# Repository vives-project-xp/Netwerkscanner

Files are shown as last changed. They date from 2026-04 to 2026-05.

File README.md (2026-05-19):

# Network Scanner





## Beschrijving

dit is een project voor het ontwikkelen van een netwerkscanner die apparaten binnen een lokaal netwerk kan detecteren en identificeren. Het project omvat zowel hardware- als softwarecomponenten en is bedoeld voor educatieve doeleinden binnen VIVES.

dit word uitgevoerd volgens de agile methodologie, met regelmatige sprints en feedback loops om continue verbetering te waarborgen.

de studenten die aan dit project werken zijn:

| Naam | github |
|---|---|
| Kyell De Windt | [](https://github.com/kyell182) |
| Ilias Lagrane | [](https://github.com/IliasLagrane) |
| Kevin Bakeland | [](https://github.com/KevinBakeland) |
| Spotnit | [](https://github.com/Spotnit) |

## testen positie bepaling
[testen van positie bepaling via wifi](./doc/positiebepaling_ideas/esp_testen.md)

## Functies

- [ ] netwerkscanning ( inkaart bregen van apparaten binnen een lokaal netwerk)
- [+] heatmap visualisatie van netwerkactiviteit
- [+] rapportage en logging van gedetecteerde apparaten
- [+] real-time monitoring dashboard

## Projectstructuur

```plaintext

Netwerkscanner/
├── hardware/
│   ├── [Hardware configuratie/schema's]
│   └── README.md
├── software/
│   ├── [Broncode bestanden]
│   └── README.md
├── doc/
│   ├── brainstorm.drawio
│   ├── RaspberryPI.md
│   └── [Overige documentatie]
├── README.md
└── .gitignore
```

## Installatie
zie documentatie

### Hardware Setup

[Beschrijving van hardware setup stappen]

### Software Setup

```bash
# Clone het repository
git clone https://github.com/vives-project-xp/Netwerkscanner.git

# Installeer dependencies
[Installatiecommando's]

# Configureer het project
[Configuratiestappen]
```

## Gebruik

```bash
# Voorbeeld command
[Hoe de scanner te gebruiken]
```

### Voorbeelden

[Praktische voorbeelden met output]

## Technologie Stack

- **Taal**: [Bijv. Python, C++, etc.]
- **Hardware**: [Bijv. Raspberry Pi, Arduino, etc.]
- **Dependencies**: [Bijv. nmap, socket, etc.]

## Status

- [x] Planning
- [x] Development
- [x] Testing
- [x] Documentation
- [x] Deployment

- [RaspberryPI Setup](doc/RaspberryPI.md)
- [Brainstorm Diagram](doc/brainstorm.drawio)
 - [Netwerkscanner Dash gebruikershandleiding](doc/netwerkscanner-dash/README.md)

##  Documentatie

### Software documentatie

#### Netwerkscanner
- [API C++ documentatie](doc/software_doc/netwerkscanner_doc/api_cpp_doc.md)
- [Device menu](doc/software_doc/netwerkscanner_doc/device_menu.md)
- [HTTP POST C++ documentatie](doc/software_doc/netwerkscanner_doc/http_post_cpp_doc.md)
- [OTA server documentatie](doc/software_doc/netwerkscanner_doc/ota_server_doc.md)
- [Screen C++ documentatie](doc/software_doc/netwerkscanner_doc/screen_cpp_doc.md)
- [Time sync documentatie](doc/software_doc/netwerkscanner_doc/time_sync_doc.md)

#### WiFi API
- [App Python documentatie](doc/software_doc/wifi-api_doc/app_py_doc.md)
- [Fingerprint Python documentatie](doc/software_doc/wifi-api_doc/fingerprint_py_doc.md)

### Overige documenten
- [Brainstorm](doc/brainstorm.drawio)
- [Fingerprint Python doc](doc/docFingerprint.py.md)
- [Projectfiche Netwerk Scanner](doc/PX%204%20-%20Projectfiche%20Netwerk%20Sca....md)
- [Roadmap](doc/readmap.md)

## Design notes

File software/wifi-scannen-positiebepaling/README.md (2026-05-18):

Deze map bevat de code voor de esp32 wroom. Deze werden gebruikt om verschilende indoor positie bepalings technieken te testen en uit te proberen.

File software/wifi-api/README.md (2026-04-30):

# Uitleg
Dit is de map met de Flask‑API en de MariaDB‑database.  
De API ontvangt Wi‑Fi scans van de ESP32, slaat ze op en bepaalt automatisch een locatie via Wi‑Fi fingerprinting.  
Je kan via de API posten naar de database en waardes kunnen opvragen.

## Hoe het werkt
- **Fingerprint**: een table waar al onze manueele scans inzitten die we gebruiken voor locatie bepaling
- **heatmap**: alle gevonden netwerken per scan gaan in deze table.
- **dev**: een table die je alleen kan opvragen met data dat niet wordt verandert, wordt gebruikt mocht een table corrupt zijn zodat dat we nog waardes kunnen opvragen.
- De fingerprinting file vergelijkt nieuwe scans met manual‑scans en vult automatisch x,y in.

## Docker
Je kan de containers starten:
- vanuit de projectroot: `docker compose up`

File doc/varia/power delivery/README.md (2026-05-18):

Deze folder is onderzoek die gedaan is maar uiteindelijk niet gebruikt.
De espc5 module (FireBeetle 2 ESP32-C5)die wij gebruiken heeft een batterij connector met bijhoorende beveiliging regeling.

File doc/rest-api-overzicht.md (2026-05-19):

# REST API overzicht

```mermaid
flowchart LR
  esp[ESP32 / Netwerkscanner] -->|GET /time| api[Flask REST API\nsoftware/wifi-api/api/app.py]
  esp -->|POST /upload| api

  ui[Dashboard / React app] -->|GET /api/heatmap| vite[Vite proxy\nsoftware/netwerkscanner-dash/vite.config.js]
  ui -->|GET/POST /projects/central.json| upload[Upload server\nsoftware/netwerkscanner-dash/file-upload-server.js]
  ui -->|POST /upload| upload

  vite -->|rewrite /api -> /| api
  upload -->|JSON + files| json[(software/assets/projectdata/central.json\n+ uploaded images)]

  api -->|MariaDB| db[(MariaDB\nheatmap, fingerprint, dev)]

  api -->|GET /heatmap| db
  api -->|GET /fingerprint| db
  api -->|GET /dev| db
  api -->|GET /predict/<id>| db
```

## Kort

- De hoofd-REST-API is de Flask-service in `software/wifi-api/api/app.py`.
- De dashboard gebruikt Vite als proxy voor `/api/*`.
- Gebouw- en vloerdata worden opgeslagen via de uploadserver in JSON en uploads in `software/assets/projectdata`.
- Scan- en fingerprintdata gaan naar MariaDB.

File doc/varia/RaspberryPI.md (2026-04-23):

#Netwerk Scanner
---

## Raspberry Pi 4

### USB
| Product / Antenne | Type / Opmerking | Frequenties | Extra info / Link |
| --- | --- | --- | --- |
| **TP‑Link Archer T2U Plus** | USB Wi‑Fi adapter met externe antennes | 2.4 / 5 GHz Dual‑Band | Goede all‑round keuze, dual-band, Linux-compatibel |
| **TP‑Link Archer T4U AC1300** | USB Wi‑Fi adapter met externe antennes | 2.4 / 5 GHz | Sterke prestaties, externe antennes |
| **BrosTrend Linux WiFi Adapter** | USB Wi‑Fi adapter | Dual-Band | Ontworpen voor Linux, goede antennes |
| **Hoco HI34 WiFi6 USB Dual Antenna** | USB Wi‑Fi adapter | Wi‑Fi 5/6 (2.4 / 5 GHz) | Wi‑Fi 6, externe antennes |
| **TP‑Link TL‑WN722N** | USB Wi‑Fi adapter met externe antenne | 2.4 GHz | Klassiker voor Raspberry Pi (2.4 GHz) |
| **Raspberry Pi sc0480 Antennekit** | Externe antenne (SMA) voor Compute Module | Dual-band Wi-Fi | Specifiek voor **CM4 externe antenne** [Kamami.pl](https://kamami.pl/en/accessories-for-raspberry-pi/1188448-sc0480-24g5g-wifi-antenna-for-raspberry-pi-compute-module-4.html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) + antenne connector dongle to usb|
| **Compute Module CM4 Antenna Kit** | Antennekit met U.FL-SMA kabel | Dual-band Wi-Fi | Kit voor **CM4**, inclusief kabel [asdstore.de](https://www.asdstore.de/cm4-cm5-antenna-kit_1?utm_source=chatgpt.com) |
| **Compatible Antenna for CM4/5** | Basis antenne voor CM4/5 | Dual-band Wi-Fi | Budget-antenne voor Compute Module + antenne connector dongle to usb |
| **Waveshare Compatibel Antenne** | Externe antenne voor CM4/5 | Dual-band Wi-Fi | Horn-antenne met SMA aansluiting [RobotShop USA](https://www.robotshop.com/products/waveshare-compatible-antenna-for-raspberry-pi-compute-module-4-24g-5g-wifi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) + antenne connector dongle to usb |
| **Waveshare CM4/5 Antenna Kit** | Complete antennekit | Dual-band Wi-Fi | Kit met accessoires, CM4/5 compatible 

### Niet USB
| Antenne | Frequentie |  Connector type | Opmerkingen |
| --- | ---: | :---: | --- |
| **[Otronic 2.4GHz WiFi antenne met SMA naar uFL/IPEX]()** | 2.4 GHz | SMA → u.FL/IPEX | Klein externe antenne met adapter → ideaal voor u.FL antenne‑connector ESP‑boards. |
| **[SMA 2.4GHz 2dB antenne]()** | 2.4 GHz | SMA | Basis omnidirectionele antenne – vereist adapter naar u.FL/IPEX om te koppelen aan ESP. |
| **[Equipment 2.4GHz antenne]()** | 2.4 GHz | (SMA/RP‑SMA)  | Externe antenne – converter kabel nodig voor aansluiting op ESP boards met u.FL. |
| **[Pinwheel 2.4GHz SMA antenne]()** | 2.4 GHz | SMA | Robuuste antenne met SMA – combineer met u.FL‑SMA pigtail. |
| **[JARFT 2.4GHz WiFi Omni antenne]()** | 2.4 GHz | RP‑SMA | All‑round antenne – goede keuze voor IoT projecten, adapter vereist. |
| **[2.4GHz Duck Antenna RP‑SMA]()** | 2.4 GHz | RP‑SMA | Whip‑antenne met rubber dop; past via adapter op boards met u.FL/IPEX. |
| **[2.4GHz Whip Rubber Antenna]()** | 2.4 GHz | SMA | Eenvoudige whip antenne – werkt met adapters. |
| **[Alfa Network 2.4GHz 15dBi omni antenne]()** | 2.4 GHz | RP‑SMA | Hoog‑gain omni antenne – geschikt voor lange‑afstand Wi‑Fi (met adapter). |
                                                                                                                                                                |
| Module | CPU / Core | Wi-Fi | Bluetooth | Externe antenne | Voordelen | Nadelen | Aanbevolen gebruik |
|---|---|---|---|---|---|---|---|
| ESP32-WROOM-32U | Dual-core 240 MHz | 2.4 GHz | BT + BLE | Ja (u.FL) | Zeer stabiel, veel support, goed voor promiscuous mode | Iets hoger verbruik | Allround netwerk scanner |
| ESP32-S3-WROOM-1U | Dual-core 240 MHz LX7 | 2.4 GHz | BLE 5 | Ja (u.FL) | Native USB, moderner, betere power management | Iets duurder | USB logging + data analyse |
| ESP32-C3-WROOM-02U | Single-core 160 MHz RISC-V | 2.4 GHz  | BLE 5 | Ja (u.FL) | Energiezuinig, compact, goedkoop | Minder rekenkracht | Batterij-geoptimaliseerde scanner |
| ESP32-C6-WROOM-1U | Single-core 160 MHz RISC-V | 2.4 GHz (Wi-Fi 6) | BLE 5 + 802.15.4 | Ja (u.FL) | Nieuwste generatie, toekomstgericht | Nog minder mature support | Experimenteel / Wi-Fi 6 scanning |
| ESP8266 (ESP-07) | Single-core 80–160 MHz | 2.4 GHz | Geen | Ja (u.FL) | Zeer goedkoop | Beperkte sniffing support, ouder | Low-budget project |

| Optie | Type | Nominale spanning | Capaciteit (typisch) | Extra elektronica nodig | Voordelen | Nadelen | Aanbevolen gebruik |
|---|---|---|---|---|---|---|---|
| USB Powerbank (5V output) | Li-ion intern | 5V uitgang | 5.000–20.000 mAh | Nee | Plug & play, ingebouwde bescherming, stabiele 5V | Minder controle over power management | Snelle prototype / eenvoudige voeding |
| 1x 18650 Li-ion cel | Li-ion | 3.7V (4.2V max) | 2.000–3.500 mAh | Ja (TP4056 + boost) | Compact, goedkoop, vervangbaar | Extra laad- en boostcircuit nodig | Custom compacte scanner |
| 2x 18650 in serie (2S) | Li-ion | 7.4V (8.4V max) | 2.000–3.500 mAh | Ja (BMS + buck converter)| Hogere efficiëntie bij buck naar 5V | Complexer, BMS vereist | Langere runtime systemen |
| 1S LiPo batterij | LiPo | 3.7V (4.2V max) | 500–5.000 mAh | Ja (laadmodule + evt. boost) | Licht, plat, ideaal voor handheld | Mechanisch gevoeliger | Compacte handheld scanner |
| 2S LiPo batterij | LiPo | 7.4V | 1.000–5.000 mAh | Ja (BMS + buck) | Efficiënte spanningsregeling mogelijk | Hogere complexiteit | Geavanceerde builds |
| 18650 DIY Powerbank module | Li-ion (18650) | 5V uitgang | Afhankelijk van cel  | Nee (meestal ingebouwd)  | Zelf cellen kiezen, 5V output | Kwaliteit varieert | Semi-custom oplossing |

## Displays:

| 5 inch touchscreen 52 euro |https://www.hobbyelectronica.nl/product/5-0-ips-capacitive-touchscreen-esp32-8048s050c-i/ |
| 4.3 inch touchscreen 39 euro | https://www.hobbyelectronica.nl/product/4-3-ips-capacitive-touchscreen-esp32-8048s043c-i |
| 3.5 inch touch 24 euro (specifiek voor ESP) | https://www.hobbyelectronica.nl/product/esp32-3-5-tft-480-320-touch/ |

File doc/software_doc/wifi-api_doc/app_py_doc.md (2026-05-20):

# APP.PY

Dit is de servercode van het project.

Via deze code weet de server wat hij moet doen met de data die de ESP verstuurt.

De server is ontwikkeld in Python met het Flask-framework.  
Hij ontvangt scandata van de ESP en slaat deze op in een MariaDB-database via een API die beschikbaar is voor het dashboard.

---

# FLASK ROUTES

Flask maakt gebruik van routes.

De server draait op:

```text
http://10.20.10.24:8081
```

## Beschikbare routes

---

## `/upload`

Dit is het eindpunt waar de ESP zijn data naartoe stuurt.

### Werking

- De server controleert of de ontvangen JSON geldig is
- Er wordt een nieuwe `scan_id` aangemaakt
  - dit is een uniek nummer voor elke scan
- De server loopt door elk netwerk in `"networks"` van de JSON
- Elk netwerk wordt opgeslagen in de database

### Locatiebepaling

Als de `Manual` waarde in de JSON gelijk is aan `0`:
- berekent de server automatisch de locatie via fingerprinting
- meer informatie hierover staat in `fingerprinting.py`

Als `Manual` niet gelijk is aan `0`:
- wordt de automatische locatiebepaling overgeslagen

Ten slotte stuurt de server een bevestiging terug naar de ESP.

---

## Opgeslagen gegevens per netwerk

| Categorie | Data |
|---|---|
| Identificatie | `ssid`, `bssid` |
| Signaal | `rssi`, `antenna` |
| Kanaal | `primary_channel`, `secondary_channel`, `bandwidth` |
| Beveiliging | `auth_mode`, `pairwise_cipher`, `group_cipher` |
| WiFi standaarden | `11b`, `11g`, `11n`, `11a`, `11ac`, `11ax` |
| Locatie | `x`, `y` |
| Tijd | `scan_time_start`, `scan_time_end` |

---

## `/heatmap`

Haalt alle opgeslagen scandata op en verstuurt deze terug als JSON.

Het dashboard gebruikt deze data om een heatmap te tekenen.

---

## `/fingerprint`

Haalt alle referentiemetingen op.

Dit zijn manuele metingen die gebruikt worden voor het fingerprinting-systeem.

---

## `/predict`

Wanneer je:

```text
/predict/"scan_id"
```

oproept, toont de server de vermoedelijke locatie van de gekozen scan.

Deze route wordt enkel gebruikt voor testen.

---

## `/dev`

Developerroute voor debugging en testen.

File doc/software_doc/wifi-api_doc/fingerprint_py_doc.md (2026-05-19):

# Fingerprinting

Deze code bepaalt de locatie van het apparaat op basis van RSSI- en BSSID-waarden.

Wanneer het apparaat RSSI- en BSSID-waarden scant, vergelijkt het systeem deze met alle opgeslagen referentiewaarden uit de database.

De referentiemeting die het meest overeenkomt met de gescande waarden wordt gebruikt als nieuwe positie van het apparaat.

---

# Hoofdfuncties

## `findLocation(scan_id)`

Vergelijkt een nieuwe scan met alle opgeslagen referentiescans in de database.

### Werking

- Haalt de BSSID- en RSSI-waarden op van de nieuwe scan
- Vergelijkt deze met alle referentiewaarden
- Berekent het verschil tussen de scans
- Slaat de resultaten op in de lijst `fingerprintScores`

---

## `findLowest(fingerprintScores)`

Zoekt de referentiescan met het kleinste verschil.

Deze scan wordt beschouwd als de meest waarschijnlijke locatie van het apparaat.

---

## `updateLocation(x, y, scan_id)`

Schrijft de gevonden coördinaten weg naar de `heatmap`-tabel in de database.

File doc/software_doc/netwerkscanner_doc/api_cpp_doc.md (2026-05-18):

# API

Zet WiFi-scandata om naar JSON en verstuurt deze naar de server.

## Functies

---

### `PrintApiInfo()`

Print alle informatie van één WiFi-netwerk naar de console.

Deze functie wordt gebruikt om data te controleren tijdens debugging, maar heeft geen directe functionele rol binnen het systeem.

---

### `GetChipId()`

Geeft een unieke naam terug, bijvoorbeeld:

```text
ESP32-C5_FFE8
```

De naam bestaat uit:
- het chiptype
- de laatste 2 bytes van het MAC-adres

Hierdoor weet de server welk apparaat de data verstuurt.

---

### `CreateWiFiJson()`

Neemt een lijst van gescande netwerken en bouwt hiervan een JSON-string.

## Parameters

| Parameter | Beschrijving |
|---|---|
| `wifi_ap_record_t* aps` | lijst van gescande netwerken |
| `uint16_t start` | vanaf welk netwerk starten |
| `uint16_t count` | hoeveel netwerken meenemen |
| `uint64_t TimeStart` | wanneer de scan begon |
| `uint64_t TimeEnd` | wanneer de scan eindigde |
| `int32_t x, y` | locatie van de scan (standaard `0,0`) |

---

# JSON Resultaat

Het resultaat ziet er als volgt uit:

```json
{
  "device_id": "ESP32-C5_FFE8",
  "scan_time_start": 10675583,
  "scan_time_end": 10675585,
  "x": 0,
  "y": 0,
  "networks": [
    {
      "ssid": "Proximus-Home",
      "rssi": -82
    },
    {
      "ssid": "Proximus-Home",
      "rssi": -91
    }
  ]
}
```

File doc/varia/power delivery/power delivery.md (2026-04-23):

# Power Delivery

```mermaid
flowchart TB

    USB_IN["USB-C 5V Input"]
    TP["TP4056 Charger"]
    BAT["2 batt parallel
    18650 Battery
    3.7V
    2500mAh + 2500mAh = 5000mAh"]
    BOOST["Boost Converter 5V"]
    ESP["ESP32-C5 Dev Board USB-C"]

    %% Laadpad
    USB_IN --> TP
    TP <--> BAT

    %% Boost voeding
    TP --> BOOST

    BOOST --> ESP

```

[TP4056 batt charger](https://opencircuit.be/product/tp4056-lipo-batterij-oplader-bescherming-1a)

[BOOST converter](https://opencircuit.be/product/boost-converter-module-5v-35v-xl6009)

[adafruit lithium 3.7V 6600mAh](https://opencircuit.be/product/lithium-ion-battery-pack-3.7v-6600mah)

[18650 lithium 3.7V 3500 mAh conrad](https://www.conrad.be/nl/p/ansmann-18650-12-60-wh-speciale-oplaadbare-batterij-18650-li-ion-3-7-v-3500-mah-1-stuk-s-1682008.html)

[ESP32-C5 Dev Board USB-C mouser 4 weken lead time](https://www.mouser.be/ProductDetail/Espressif-Systems/ESP32-C5-DevKitC-1-N8R8?qs=6avfeC6zeS67aD1hu9NHBw%3D%3D)

[ESP32-C5 Dev Board USB-C digi-key 19 weken?? lead time](https://www.digikey.be/en/products/detail/espressif-systems/ESP32-C5-DEVKITC-1-N8R8/28718162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)

[batt houder 18650](https://opencircuit.be/product/battery-holder-1x18650-wire-leads)

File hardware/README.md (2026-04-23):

# Hardware map

Deze map bevat alles wat nodig is voor de hardwarekant van de Netwerkscanner. Het doel is om de fysieke opstelling, schema’s en configuraties te documenteren zodat de hardware gemakkelijk opgebouwd, nagekeken en gereproduceerd kan worden.

Wat je hier kan verwachten:

- Schema’s en bekabelingsplannen.
- Overzicht van gebruikte componenten en hun specificaties.
- Opbouw- en testinstructies voor de hardware.
- Eventuele foto’s of meetresultaten die de hardwarekeuzes onderbouwen.

Gebruik deze map om de hardware-opzet consequent te houden en duidelijke referentie te bieden voor teamleden en begeleiders.

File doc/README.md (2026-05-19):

# Documentatie map

[ftm research](./varia/esp/ftm%20research.md)  
[wifi research](./varia/esp/wifi%20research.md)  
[wifi handige img](./varia/assets/)  
[docker/fingerprinting](./docFingerprint.py.md)
[REST API overzicht](./rest-api-overzicht.md)

Deze map bevat alle projectdocumentatie voor de Netwerkscanner. Het doel is om de keuzes, ontwerpen en instructies die niet in de broncode thuishoren, centraal te bewaren zodat het project makkelijk te begrijpen, te onderhouden en te presenteren is.

Wat je hier kan verwachten:

- Ontwerp- en brainstormbestanden die de richting van het project tonen.
- Technische uitleg en installatiestappen, bijvoorbeeld voor hardware of een specifieke setup.
- Aanvullende notities, beslissingen en achtergronddocumentatie die tijdens het project werden gemaakt.

Gebruik deze map om documentatie up-to-date te houden en ervoor te zorgen dat nieuwe teamleden of begeleiders snel inzicht krijgen in de aanpak en werking van het project.

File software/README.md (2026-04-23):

# Software map

Deze map bevat alle broncode en softwaregerelateerde onderdelen van de Netwerkscanner. Het doel is om de implementatie gestructureerd te bewaren en duidelijk te maken hoe de software is opgebouwd en gebruikt kan worden.

Wat je hier kan verwachten:

- Broncodebestanden en modules van de scanner.
- Configuratiebestanden en voorbeeldinstellingen.
- Scripts voor installatie, build of deployment.
- Eventuele testbestanden en hulpmiddelen voor debugging.

Gebruik deze map om de software logisch te organiseren en de ontwikkeling en het onderhoud te vergemakkelijken.

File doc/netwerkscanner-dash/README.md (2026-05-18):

# Netwerkscanner Dashboard - Volledige Documentatie

## Inhoudsopgave

1. [Overzicht](#overzicht)
2. [Snelle Start](#snelle-start)
3. [Project Structuur](#project-structuur)
4. [Technologie Stack](#technologie-stack)
5. [Functionaliteiten](#functionaliteiten)
6. [Gebruikshandleiding](#gebruikshandleiding)
7. [Ontwikkelaars Gids](#ontwikkelaars-gids)

---

## Overzicht

Het **Netwerkscanner Dashboard** is een webgebaseerde applicatie voor het beheren en visualiseren van draadloze netwerken in gebouwen. Het systeem stelt gebruikers in staat om:

- Gebouwen en verdiepingen te beheren
- WiFi-signaalsterkte (RSSI) gegevens te visualiseren
- Toegangspunten (Access Points) in kaarten in te tekenen
- Projectgegevens op te slaan en te delen

### Voor wie is dit?

- **Eindgebruikers**: IT-beheerders en netwerkspecialisten
- **Ontwikkelaars**: Backend engineers en frontend developers die het systeem uitbreiden
- **Iedereen**: De interface is intuïtief genoeg om zonder technische achtergrond te gebruiken

---

## Snelle Start

### Vereisten

- Docker en Docker Compose geïnstalleerd
- Git (om het project te clonen)

### Instalatie

1. **Clone het project**

   ```bash
   git clone <repository-url>
   cd Netwerkscanner
   ```

2. **Maak een `.env` bestand** in de projectroot

   ```env
   MYSQL_ROOT_PASSWORD=your_root_password
   MYSQL_DATABASE=netwerkscanner_db
   MYSQL_USER=scanner_user
   MYSQL_PASSWORD=scanner_password
   ```

3. **Start de applicatie via Docker Compose**

   ```bash
   docker-compose up
   ```

4. **Open je browser**

   - Dashboard: http://localhost
   - Upload Server: http://localhost:3030

### Afsluiten

```bash
docker-compose down
```

---

## Project Structuur

```
netwerkscanner-dash/
├── src/                      # React source code
│   ├── components/          # Herbruikbare UI-componenten
│   ├── pages/              # Volledige paginaweergaven
│   ├── hooks/              # Custom React hooks
│   ├── entities/           # Gegevensmodellen
│   ├── assets/             # Afbeeldingen en media
│   ├── App.jsx             # Hoofdtoepassing
│   ├── main.jsx            # React entry point
│   ├── index.css           # Globale stijlen
│   └── App.css             # App-specifieke stijlen
│
├── public/                  # Statische bestanden
├── dist/                    # Build output (gegenereerd)
│
├── Dockerfile              # Docker configuratie
├── docker-compose.yml      # Services orchestratie
├── package.json            # Dependencies en scripts
├── vite.config.js          # Vite bundler configuratie
├── tailwind.config.js      # Tailwind CSS configuratie
├── postcss.config.js       # PostCSS configuratie
├── eslint.config.js        # Code quality configuratie
│
├── file-upload-server.js   # Node.js upload server
├── index.html              # HTML template
└── README.md               # Dit bestand
```

---

## Technologie Stack

| Laag | Technologie | Functie |
| --- | --- | --- |
| **Frontend** | React 19 | UI Framework |
| **Build Tool**  | Vite | Snelle build & dev server |
| **Styling** | Tailwind CSS 4 | Utility-first CSS |
| **Icons** | Lucide React | Icon library |
| **Backend** | Express.js | File upload server |
| **HTTP Client** | Axios | API requests |
| **Storage** | IndexedDB | Lokale client-side data |
| **Deployment**  | Docker | Containerization |

---

## Functionaliteiten

### Hoofdscherm (Dashboard)

- Snelle statistieken weergeven
- Actieve projects bekijken
- Snelle navigatie naar andere secties

### Gebouwen Beheren

- **Toevoegen**: Nieuwe gebouwen creëren met naam en details
- **Verwijderen**: Gebouwen verwijderen (met bevestiging)
- **Selecteren**: Een gebouw kiezen om in detail te bewerken

### Gebouwdetails

- **Verdiepingen**: Meerdere verdiepingen per gebouw toevoegen
- **Verdiepingskaarten**: Plattegronden uploaden als afbeeldingen
- **Access Points**: WiFi-punten op kaarten plaatsen
- **RSSI-gegevens**: Signaalsterktegegevens visualiseren

---

## Gebruikshandleiding

### 1. Een Nieuw Project Starten

**Stap 1: Ga naar "Gebouwen"**

- Klik op "Gebouwen" in het linkermenu

**Stap 2: Voeg een gebouw toe**

- Klik "Nieuw Gebouw"
- Vul gebouwgegevens in (naam, adres, etc.)
- Klik "Opslaan"

**Stap 3: Voeg verdiepingen toe**

- Klik op het gebouw om details te openen
- Klik "Voeg verdieping toe"
- Vul verdiepingsnummer in
- Upload een afbeelding van de plattegrond

### 2. Access Points Plaatsen

**Stap 1: Selecteer een verdieping**

- Open het gebouw en selecteer de verdieping in de FloorSelector

**Stap 2: Upload/Bekijk de plattegrond**

- De plattegrondafbeelding wordt weergegeven
- Je kunt in/uit zoomen en pannen met muisgestures

**Stap 3: Voeg Access Points toe**

- Klik op "Access Points Toevoegen" in het linker menu
- Klik op de kaart om een punt toe te voegen
- Vul de BSSID (MAC-adres) in
- Vul de signaalsterkte (RSSI) in
- Sla op

### 3. Gegevens Exporteren

**Projectgegevens opslaan**

- De app slaat automatisch op in IndexedDB
- Download volledige projectdata via het menu

**Projectgegevens importeren**

- Kies "Importeren" in het menu
- Selecteer een eerder gedownload JSON-bestand
- De gegevens worden hersteld

---

##  Ontwikkelaars Gids

### Lokale Ontwikkeling Starten

```bash
# Installeer dependencies
npm install

# Start development server + upload server
npm run dev:full

# Of aparte commands:
npm run dev              # Vite dev server (poort 5173)
npm run upload-server    # Upload server (poort 3030)
```

### Project Structuur Documentatie

#### [**App.jsx**](./COMPONENTS.md#appjsx)

Hoofdtoepassing met tab-navigatie en state management.

#### [**file-upload-server.js**](./FILE_SERVER.md)

Express server voor bestandsuploads en projectgegevensbeheer.

#### [**src/components/**](./COMPONENTS.md#components)

Herbruikbare UI-componenten voor verschillende functionaliteiten.

#### [**src/pages/**](./PAGES.md)

Volledige paginaweergaven (Dashboard, Buildings, BuildingDetail).

#### [**src/hooks/**](./HOOKS.md)

Custom React hooks voor data fetching en state management.

#### [**Configuratiebestanden**](./CONFIG.md)

- `vite.config.js` - Build configuratie
- `tailwind.config.js` - Styling setup
- `docker-compose.yml` - Service orchestratie
- `.env` - Omgevingsvariabelen

### Build en Deployment

```bash
# Production build
npm run build

# Preview production build
npm run preview

# Lint code
npm run lint
```

### Docker Development

```bash
# Build services
docker-compose build

# Start met live reload
docker-compose up

# Kijk logs
docker-compose logs -f network-scanner

# Stop services
docker-compose down
```

### API Integratie

De app maakt verbinding met:

- **WiFi API**: `http://10.20.10.24:8081` (naar `/api` proxy)
- **Upload Server**: `http://localhost:3030` (lokaal)

Alle routes worden geproxied via `vite.config.js`.

---

## Gedetailleerde Documentatie

Zie de volgende bestanden voor meer details:

- **[COMPONENTS.md](./COMPONENTS.md)** - Beschrijving van alle React componenten
- **[PAGES.md](./PAGES.md)** - Pagina-logica en flow
- **[HOOKS.md](./HOOKS.md)** - Custom React hooks
- **[FILE_SERVER.md](./FILE_SERVER.md)** - Upload server API
- **[CONFIG.md](./CONFIG.md)** - Configuratiebestanden uitgelegd
- **[API.md](./API.md)** - API endpoints en integratie

---

## Probleemoplossing

### Dashboard laadt niet

- Controleer of alle Docker services draaien: `docker-compose ps`
- Controleer de browser console voor fouten

### Upload server werkt niet

- Controleer poort 3030: `netstat -an | grep 3030`
- Check Docker logs: `docker-compose logs upload-server`

### IndexedDB fouten

- Wis browsercache: DevTools > Application > Clear Site Data
- Reset IndexedDB database manueel

### Vite build fouten

- Verwijder `node_modules` en `dist`
- Herinstalleer: `npm install && npm run build`

---

**Laatst bijgewerkt**: 2026
**Versie**: 1.0.0

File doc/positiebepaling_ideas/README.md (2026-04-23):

Deze folder bevat informatie over hoe indoor positie bepaling kan werken.

Voor de eigen uitgevoerde testen moet je hier zijn [esp_testen.md](esp_testen.md) zijn.

links naar websites en video's kan je hier vinden [links.md](links.md).

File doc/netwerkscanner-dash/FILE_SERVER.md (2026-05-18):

# File Upload Server - API Documentatie

**Bestand**: `file-upload-server.js`

---

## Overzicht

Een **Express.js server** die twee kernfunctionaliteiten biedt:

1. **Bestandsuploads** - Plattegrondafbeeldingen en project media
2. **Project Data Management** - Opslag en ophalen van project configuraties

---

## Configuratie

### Server Details

- **Port**: 3030
- **Host**: 0.0.0.0 (all interfaces)
- **Upload Map**: `../assets/projectdata`
- **Project File**: `../assets/projectdata/central.json`

### Environment

```javascript
UPLOAD_DIR = './software/assets/projectdata'
PROJECTS_FILE = './software/assets/projectdata/central.json'
```

### Startup

```bash
node file-upload-server.js
```

Of via npm:

```bash
npm run upload-server
```

---

## API Endpoints

### 1. Bestandsupload

**Endpoint**: `POST /upload`

**Content-Type**: `multipart/form-data`

**Request**:

```bash
curl -X POST \
  -F "file=@plattegrond.jpg" \
  http://localhost:3030/upload
```

**Response** (200 OK):

```json
{
  "filename": "1234567890-plattegrond.jpg",
  "url": "/assets/projectdata/1234567890-plattegrond.jpg"
}
```

**Error Response** (400):

```json
{
  "error": "No file uploaded"
}
```

**Details**:

- Maximale bestandsgrootte: 10 MB (kan aangepast in `express.json()`)
- Bestandsnaam: `{timestamp}-{originalname}`
- Bestand opgeslagen in: `/assets/projectdata/`

---

### 2. Project Data Ophalen

**Endpoint**: `GET /projects/central.json`

**Response** (200 OK):

```json
[
  {
    "id": "building-1",
    "name": "Kantoor A",
    "address": "Straat 123",
    "floors": [
      {
        "id": "floor-1",
        "number": 1,
        "name": "Begane grond",
        "imageUrl": "/assets/projectdata/1234567890-plattegrond.jpg",
        "accessPoints": [
          {
            "id": "ap-1",
            "bssid": "00:11:22:33:44:55",
            "rssi": -45,
            "x": 150,
            "y": 200
          }
        ]
      }
    ]
  }
]
```

**Details**:

- Retourneert altijd een array
- Als bestand niet bestaat, retourneert lege array
- Als bestand corrupt is, retourneert lege array (geen error)

---

### 3. Project Data Opslaan

**Endpoint**: `POST /projects/central.json`

**Content-Type**: `application/json`

**Request**:

```json
[
  {
    "id": "building-1",
    "name": "Kantoor A",
    "floors": []
  }
]
```

**Response** (200 OK):

```json
{
  "ok": true
}
```

**Error Response** (500):

```json
{
  "ok": false,
  "error": "Save failed"
}
```

**Details**:

- Payload moet array zijn
- Pretty-printed JSON (2 spaties indent)
- Overschrijft bestaand bestand volledig
- Synchrone operatie (blokkering)

---

## File Upload Verwerking

### Upload Map Structuur

```txt
assets/projectdata/
├── central.json              # Hoofd project data
├── 1234567890-plan1.jpg
├── 1234567890-plan2.png
└── 1234567890-netwerk.svg
```

### Bestandsnaamgeneratie

```javascript
const uniqueSuffix = Date.now() + '-' + Math.round(Math.random() * 1E9);
const filename = uniqueSuffix + '-' + originalname;
// Voorbeeld: 1684923456789-0123456789-plattegrond.jpg
```

### Originalename behouden

- Originele bestandsnaam blijft behouden
- Unieke prefix voorkomt overwrite
- Ondersteunt alle bestandstypes (jpg, png, svg, etc.)

---

## Security Features

### CORS

```javascript
app.use(cors());  // Allow all origins
```

- Alle cross-origin requests toegestaan
- Production: Beperk tot specifieke domains

### Payload Limits

```javascript
express.json({ limit: '10mb' })  // Max JSON size
```

- Verhoog indien nodig voor grotere projecten
- Default multer: unlimited

### Bestandsvalidatie

```javascript
if (!req.file) return res.status(400).json({ error: 'No file uploaded' })
```

- Controleert bestandsexistentie
- Retourneert 400 Bad Request als missing

---

## 🔄 Data Workflow

### Upload Flow

```txt
Browser Form
    ↓
POST /upload (multipart)
    ↓
Multer Middleware
    ↓
File geschreven naar disk
    ↓
Response met filename
```

### Project Save Flow

```txt
React App
    ↓
POST /projects/central.json
    ↓
JSON Validatie
    ↓
fs.writeFileSync()
    ↓
Response { ok: true }
```

### Project Load Flow

```txt
Browser
    ↓
GET /projects/central.json
    ↓
fs.readFileSync()
    ↓
JSON Parse & Validate
    ↓
Response Array
```

---

## Integratie met Vite

In `vite.config.js`:

```javascript
'/upload': {
  target: env.VITE_UPLOAD_SERVER || 'http://localhost:3030',
  changeOrigin: true
},
'/projects': {
  target: env.VITE_UPLOAD_SERVER || 'http://localhost:3030',
  changeOrigin: true
},
'/assets/projectdata': {
  target: env.VITE_UPLOAD_SERVER || 'http://localhost:3030',
  changeOrigin: true
}
```

**ProxyMapping**:

- `/upload` → `http://localhost:3030/upload`
- `/projects` → `http://localhost:3030/projects`
- `/assets/projectdata` → `http://localhost:3030/assets/projectdata`

---

## Voorbeeld React Integratie

### Bestand Uploaden

```jsx
const uploadFile = async (file) => {
  const formData = new FormData();
  formData.append('file', file);
  
  const response = await axios.post('/upload', formData, {
    headers: { 'Content-Type': 'multipart/form-data' }
  });
  
  return response.data.url;
};
```

### Project Laden

```jsx
const loadProject = async () => {
  const response = await axios.get('/projects/central.json');
  return response.data;
};
```

### Project Opslaan

```jsx
const saveProject = async (buildingsData) => {
  const response = await axios.post('/projects/central.json', buildingsData);
  return response.data.ok;
};
```

---

## Error Handling

| Situatie | Status | Response |
| --- | --- | --- |
| Geen bestand geupload | 400 | `{ error: "No file uploaded" }` |
| Corrupte JSON | 200 | `[]` (lege array) |
| File save failure | 500 | `{ ok: false, error: "Save failed" }` |
| Ongeldige payload | 200 | `[]` (ignored) |

**Note**: GET request kan geen echte 404 geven - altijd 200 met array

---

## Performance Tips

### Bestandsgrootte

- Comprimeer afbeeldingen vooraf
- Gebruik WebP voor moderne browsers
- Max 10MB per file (configureerbaar)

### Database Schaling

- `central.json` kan groot worden (>50MB)
- Voor productie: Migrate naar SQLite of PostgreSQL
- Implementeer pagination voor grote datasets

### Server Optimization

```javascript
// Momenteel: Sync file operations
// Better: Async operaties
const response = await fs.promises.readFile(...)
const response = await fs.promises.writeFile(...)
```

---

## Docker Deployment

In `docker-compose.yml`:

```yaml
upload-server:
  build:
    context: ./software/netwerkscanner-dash
  container_name: upload-server
  command: npm run upload-server
  volumes:
    - ./software/assets/projectdata:/assets/projectdata
  ports:
    - "3030:3030"
```

**Volume Mount**: Persistente opslag van uploads

---

## Backup & Recovery

### Backup van Projects

```bash
# Backup central.json
cp software/assets/projectdata/central.json backup.json
```

### Restore van Backup

```bash
# Restore central.json
cp backup.json software/assets/projectdata/central.json
```

### Uploaded Files

Alle geupload bestanden in `software/assets/projectdata/` zijn persistent via Docker volume.

---

## Toekomstige Verbeteringen

- [ ] Async/await refactoring
- [ ] SQLite database ipv JSON
- [ ] File versioning
- [ ] Bestandsvalidatie (type checking)
- [ ] Compression algoritmes
- [ ] Rate limiting
- [ ] Authentication/Authorization
- [ ] File deletion endpoints

---

**Voor meer info zie**: [README.md](./README.md)

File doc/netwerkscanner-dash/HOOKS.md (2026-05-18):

# Hooks - Custom React Logic

**Locatie**: `src/hooks/`

---

## useBuildings Hook

**Bestand**: `src/hooks/useBuildings.js`

### Doel

Centraal beheer van gebouw data met:
- Laden van IndexedDB
- CRUD operaties
- Synchronisatie met upload server
- Loading state

### Signature

```javascript
function useBuildings() {
  return {
    buildings: Building[],
    addBuilding: (data) => void,
    deleteBuilding: (id) => void,
    addFloor: (buildingId, data) => void,
    deleteFloor: (buildingId, floorId) => void,
    isLoaded: boolean
  };
}
```

### Return Object

```javascript
{
  buildings: [
    {
      id: "building-1",
      name: "Kantoor A",
      address: "Straat 123",
      floors: [
        {
          id: "floor-1",
          number: 1,
          name: "Begane grond",
          imageUrl: "/assets/projectdata/image.jpg",
          accessPoints: [
            {
              id: "ap-1",
              bssid: "00:11:22:33:44:55",
              rssi: -45,
              x: 150,
              y: 200
            }
          ]
        }
      ]
    }
  ],
  isLoaded: true
}
```

### Functies

#### addBuilding(data)

```javascript
const { addBuilding } = useBuildings();

addBuilding({
  name: "Kantoor B",
  address: "Laan 456"
});
```

**Workflow**:
1. Genereer unieke ID
2. Voeg toe aan local state
3. Opslaan in IndexedDB
4. Synchroniseer met server

#### deleteBuilding(id)

```javascript
deleteBuilding("building-1");
```

**Workflow**:
1. Verwijder uit state
2. Verwijder uit IndexedDB
3. Update server

#### addFloor(buildingId, data)

```javascript
addFloor("building-1", {
  number: 2,
  name: "Eerste verdieping"
});
```

**Workflow**:
1. Vind gebouw
2. Voeg verdieping toe
3. Persisteer in IndexedDB
4. Synchroniseer

#### deleteFloor(buildingId, floorId)

```javascript
deleteFloor("building-1", "floor-2");
```

**Workflow**:
1. Vind en verwijder verdieping
2. Update state
3. Persisteer

### IndexedDB Integration

**Database**: `netwerkscanner_db`
**Store**: `buildings`

```javascript
// Internal operations
idbKeyval.get('buildings')      // Ophalen
idbKeyval.set('buildings', data) // Opslaan
```

### Server Synchronisatie

**Endpoints**:
- `GET /projects/central.json` - Laden
- `POST /projects/central.json` - Opslaan

**Auto-sync**:
- Op initialization laden
- Na elke CRUD operatie opslaan
- Error handling met fallback

### Voorbeeld Gebruik

```jsx
import { useBuildings } from './hooks/useBuildings';

export default function MyComponent() {
  const { buildings, addBuilding, isLoaded } = useBuildings();

  if (!isLoaded) return <div>Laden...</div>;

  return (
    <div>
      <h1>{buildings.length} gebouwen</h1>
      <button onClick={() => addBuilding({ name: 'Nieuw' })}>
        Toevoegen
      </button>
    </div>
  );
}
```

---

## Hook Architecture

### State Management Flow

```
useBuildings Hook
    ↓
useState(buildings)
    ↓
useEffect (initialization)
    ↓
Load from IndexedDB
    ↓
Load from Server (if sync)
    ↓
Update State
```

### Lifecycle

**Mount**:
1. Initialiseer lege state
2. Set `isLoaded = false`
3. Load van IndexedDB
4. Load van server
5. Merge data
6. Set `isLoaded = true`

**Update**:
1. Muteer local state
2. Opslaan in IndexedDB
3. Synchroniseer met server
4. Trigger re-render

**Unmount**:
- Automatische cleanup
- Alle subscriptions verwijderd

---

## Data Persistentie

### IndexedDB vs Server

| Aspect | IndexedDB | Server |
|---|---|---|
| Locatie | Browser | Disk |
| Speed | Instant | Network latency |
| Sync | Manueel | Bij save |
| Offline | Ja | Nee |

### Sync Strategy

```javascript
// Load phase
const local = await indexedDB.get()
const remote = await fetch('/projects/central.json')
const merged = mergeData(local, remote)

// Save phase
await indexedDB.set(data)
await fetch('/projects/central.json', { method: 'POST', body: data })
```

---

## Error Handling

### Try-Catch Patterns

```javascript
try {
  const data = await idbKeyval.get('buildings')
  if (!data) {
    // Initialize new
  }
} catch (error) {
  console.error('IndexedDB error:', error)
  // Fallback to server
}
```

### Network Errors

```javascript
try {
  await axios.post('/projects/central.json', data)
} catch (error) {
  // Data still in IndexedDB - not lost
  console.error('Server save failed')
}
```

---

## Performance Optimizations

### Memoization

```javascript
const buildings = useMemo(() => {
  return rawBuildings.filter(...)
}, [rawBuildings])
```

### Lazy Loading

Gebouwen worden lazily geladen:
- Index eerst
- Details on demand
- Access points op interactie

### Batch Operations

```javascript
// Bad - multiple saves
addBuilding(data1)
addBuilding(data2)
addBuilding(data3)

// Good - batch update
addBuildingBatch([data1, data2, data3])
```

---

## Testing Hook

### Unit Test Voorbeeld

```javascript
import { renderHook, act } from '@testing-library/react'
import { useBuildings } from './useBuildings'

test('adds building', () => {
  const { result } = renderHook(() => useBuildings())
  
  act(() => {
    result.current.addBuilding({ name: 'Test' })
  })
  
  expect(result.current.buildings).toHaveLength(1)
})
```

### Integration Test

```javascript
test('saves and loads building', async () => {
  const { result } = renderHook(() => useBuildings())
  
  await waitFor(() => {
    expect(result.current.isLoaded).toBe(true)
  })
  
  act(() => {
    result.current.addBuilding({ name: 'Test' })
  })
  
  // Verify in IndexedDB
  const saved = await idbKeyval.get('buildings')
  expect(saved).toBeDefined()
})
```

---

## Advanced Patterns

### Custom Hook Composition

```javascript
function useBuildingWithFloors(buildingId) {
  const { buildings } = useBuildings()
  return useMemo(() => {
    return buildings.find(b => b.id === buildingId)
  }, [buildings, buildingId])
}
```

### State Reducer Pattern

```javascript
function useReducerBuildings() {
  const [state, dispatch] = useReducer(buildingReducer, initialState)
  
  return {
    buildings: state.buildings,
    dispatch
  }
}
```

### Custom Hook with Args

```javascript
function useBuilding(buildingId) {
  const { buildings } = useBuildings()
  return buildings.find(b => b.id === buildingId)
}

// Usage
const building = useBuilding('building-1')
```

---

## Common Issues & Solutions

### Hook Called Conditionally

❌ **Wrong**:
```javascript
if (someCondition) {
  const { buildings } = useBuildings()
}
```

✅ **Correct**:
```javascript
const { buildings } = useBuildings()
if (someCondition) {
  // use buildings
}
```

### IndexedDB Quota

**Problem**: Storage vul vol
**Solution**: 
```javascript
// Check quota
navigator.storage?.estimate()

// Clear old data
idbKeyval.delete('old_key')
```

### Stale Closures

❌ **Wrong**:
```javascript
const x = buildings
setTimeout(() => {
  console.log(x) // May be stale
}, 1000)
```

✅ **Correct**:
```javascript
useEffect(() => {
  // Re-run when buildings change
}, [buildings])
```

---

## Migration Guide

### From Props Drilling

**Before**:
```javascript
<Parent>
  <Child buildings={buildings}>
    <Grandchild buildings={buildings} />
  </Child>
</Parent>
```

**After**:
```javascript
function Child() {
  const { buildings } = useBuildings()
  return <Grandchild />
}

function Grandchild() {
  const { buildings } = useBuildings()
  return ...
}
```

---

## Future Improvements

- [ ] Add TypeScript definitions
- [ ] Implement optimistic updates
- [ ] Add offline sync queue
- [ ] Implement cache invalidation
- [ ] Add subscription system
- [ ] Performance metrics tracking

---

**Voor meer info zie**: [README.md](./README.md)

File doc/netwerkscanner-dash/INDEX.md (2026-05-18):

# Netwerkscanner Dashboard - Documentatie Index

Welkom bij de volledige documentatie van het Netwerkscanner Dashboard. Dit document helpt je het juiste document te vinden voor jouw gebruik.

---

## 📖 Documentatie per Rol

### 👤 Voor Eindgebruikers & IT-Beheerders

**Start hier**: [Gebruikshandleiding](./USERGUIDE.md)

- Hoe het systeem starten
- Gebouwen en verdiepingen beheren
- Access Points plaatsen
- Project gegevens opslaan/importeren
- Veelgestelde vragen
- Troubleshooting

**Duur**: 15-20 minuten leestijd

---

### 👨‍💻 Voor Ontwikkelaars

**Start hier**: [README.md](./README.md) - Developers Gids

Dit bevat:
- Project structuur overzicht
- Snelle start instructies
- Docker setup
- Links naar technische documentatie

---

### 🚀 Voor DevOps & Systeembeheerders

**Relevante secties**:
1. [README.md](./README.md#snelle-start) - Docker Compose setup
2. [CONFIG.md](./CONFIG.md) - Configuratiebestanden
3. [FILE_SERVER.md](./FILE_SERVER.md) - Upload server deployment

---

## 📚 Volledige Documentatie Map

### Gids Documents

| Document | Onderwerp | Voor | Duur |
|---|---|---|---|
| [README.md](./README.md) | Volledige project overzicht | Iedereen | 30 min |
| [USERGUIDE.md](./USERGUIDE.md) | Praktische gebruikershandleiding | Eindgebruikers | 20 min |
| [COMPONENTS.md](./COMPONENTS.md) | React componenten uitleg | Developers | 25 min |
| [FILE_SERVER.md](./FILE_SERVER.md) | Upload server API | Backend devs | 20 min |
| [HOOKS.md](./HOOKS.md) | Custom React hooks | Frontend devs | 20 min |
| [CONFIG.md](./CONFIG.md) | Configuratie bestanden | DevOps | 25 min |
| [API.md](./API.md) | API integratie & proxy | Developers | 20 min |

---

## 🎯 Snelle Links op Onderwerp

### Installatie & Setup

- [Quick Start](./README.md#snelle-start)
- [Docker Compose Setup](./README.md#snelle-start)
- [Environment Variables](./CONFIG.md#env-file)
- [Port Configuration](./CONFIG.md#vite-configjs)

### Gebruikershandleiding

- [Aan de slag](./USERGUIDE.md#aan-de-slag)
- [Gebouwen beheren](./USERGUIDE.md#gebouwen-beheren)
- [Access Points plaatsen](./USERGUIDE.md#access-points-plaatsen)
- [Project data](./USERGUIDE.md#project-gegevens)
- [FAQ](./USERGUIDE.md#veelgestelde-vragen)

### Technische Architectuur

- [Project Structuur](./README.md#project-structuur)
- [Technologie Stack](./README.md#technologie-stack)
- [Component Hierarchie](./COMPONENTS.md#component-hierarchie)
- [Data Flow](./COMPONENTS.md#data-flow)

### Backend & APIs

- [File Upload Server](./FILE_SERVER.md)
- [API Endpoints](./FILE_SERVER.md#-api-endpoints)
- [API Integratie](./API.md)
- [Proxy Configuration](./API.md#-proxy-configuration)

### Frontend Components

- [App.jsx](./COMPONENTS.md#appjsx)
- [Pages](./COMPONENTS.md#pages)
- [Components](./COMPONENTS.md#components)
- [Custom Hooks](./HOOKS.md)

### Configuratie

- [package.json](./CONFIG.md#-packagejson)
- [vite.config.js](./CONFIG.md#-viteconfigjs)
- [Dockerfile](./CONFIG.md#-dockerfile)
- [docker-compose.yml](./CONFIG.md#-docker-composeyml)
- [Tailwind Config](./CONFIG.md#-tailwindconfigjs)
- [ESLint Config](./CONFIG.md#-eslintconfigjs)

### Problemen Oplossen

- [Troubleshooting](./README.md#-probleemoplossing)
- [Error Handling](./API.md#-error-handling)
- [Common Issues](./HOOKS.md#common-issues--solutions)

---

## 📊 Documento Structuur

```
doc/
└── netwerkscanner-dash/
    ├── README.md              # Hoofd documentatie
    ├── USERGUIDE.md           # Voor eindgebruikers
    ├── COMPONENTS.md          # React componenten
    ├── FILE_SERVER.md         # Upload server
    ├── HOOKS.md               # Custom hooks
    ├── CONFIG.md              # Configuratie
    ├── API.md                 # API integratie
    └── INDEX.md               # Dit document
```

---

## 🚀 Aan de Slag Scenario's

### Scenario 1: Ik wil het dashboard gebruiken

1. Lees: [USERGUIDE.md](./USERGUIDE.md)
2. Start: Docker Compose (zie [README.md](./README.md#snelle-start))
3. Open: http://localhost
4. Volg: Stap-voor-stap instructies

**Tijd**: ~30 minuten

---

### Scenario 2: Ik wil het lokaal ontwikkelen

1. Lees: [README.md - Developers Gids](./README.md#-ontwikkelaars-gids)
2. Installeer: `npm install`
3. Start: `npm run dev:full`
4. Lees: [COMPONENTS.md](./COMPONENTS.md) voor componenten
5. Lees: [CONFIG.md](./CONFIG.md) voor instellingen

**Tijd**: ~45 minuten

---

### Scenario 3: Ik wil het in productie deployen

1. Lees: [README.md - Docker Deployment](./README.md#docker-development)
2. Lees: [CONFIG.md - Configuration](./CONFIG.md)
3. Setup: Environment variables (`.env`)
4. Deploy: `docker-compose up -d`
5. Monitor: Docker logs

**Tijd**: ~1 uur

---

### Scenario 4: Ik wil een nieuw feature toevoegen

1. Lees: [COMPONENTS.md - Structuur](./COMPONENTS.md#component-architectuur)
2. Lees: [HOOKS.md - State Management](./HOOKS.md)
3. Lees: [API.md - Integratie](./API.md)
4. Maak: Nieuwe component/hook
5. Test: Lokaal met `npm run dev`

**Tijd**: Afhankelijk van feature

---

## 🔗 Externe Referenties

### Technologie Documentatie

- [React](https://react.dev)
- [Vite](https://vitejs.dev)
- [Tailwind CSS](https://tailwindcss.com)
- [Express.js](https://expressjs.com)
- [Docker](https://docs.docker.com)

### Bibliotheken

- [Lucide React Icons](https://lucide.dev)
- [Axios HTTP Client](https://axios-http.com)
- [IndexedDB](https://developer.mozilla.org/en-US/docs/Web/API/IndexedDB_API)

---

## ❓ Veel Gestelde Vragen

### V: Welk document moet ik lezen?

**A**: 
- Eindgebruiker? → [USERGUIDE.md](./USERGUIDE.md)
- Developer? → [README.md](./README.md)
- DevOps? → [CONFIG.md](./CONFIG.md)
- Alle onderdelen? → Lees alles in volgorde

---

### V: Hoe installeer ik het systeem?

**A**: Zie [README.md - Snelle Start](./README.md#snelle-start) voor stap-voor-stap instructies.

---

### V: Welke poorten worden gebruikt?

**A**: 
- Port 80: Dashboard
- Port 3030: Upload Server
- Port 3306: Database
- Port 8081: WiFi API

Zie [docker-compose.yml](./CONFIG.md#-docker-composeyml) voor details.

---

### V: Kan ik componenten uitbreiden?

**A**: Ja! Zie [COMPONENTS.md - Uitbreiding](./COMPONENTS.md#uitbreiding) voor template.

---

### V: Hoe debug ik API calls?

**A**: Zie [API.md - Debugging](./API.md#-debugging-api-calls).

---

## 📋 Documentatie Checklist

Zorg dat je het volgende hebt:

- [ ] [README.md](./README.md) - Project overzicht
- [ ] Relevante rol-gebaseerde gids:
  - [ ] [USERGUIDE.md](./USERGUIDE.md) - Voor eindgebruikers
  - [ ] [COMPONENTS.md](./COMPONENTS.md) - Voor developers
  - [ ] [CONFIG.md](./CONFIG.md) - Voor DevOps
- [ ] [FILE_SERVER.md](./FILE_SERVER.md) - Voor upload/storage
- [ ] [HOOKS.md](./HOOKS.md) - Voor state management
- [ ] [API.md](./API.md) - Voor integratie

---

## 🎓 Leesvolgorde Aanbevelingen

### Voor Eindgebruikers (30 min)
1. [USERGUIDE.md](./USERGUIDE.md) - Compleet

### Voor Frontend Developers (90 min)
1. [README.md](./README.md) - Overzicht
2. [COMPONENTS.md](./COMPONENTS.md) - Alle secties
3. [HOOKS.md](./HOOKS.md) - Custom logic
4. [CONFIG.md](./CONFIG.md) - Vite & Tailwind
5. [API.md](./API.md) - Integratie

### Voor Backend Developers (60 min)
1. [README.md](./README.md) - Overzicht
2. [FILE_SERVER.md](./FILE_SERVER.md) - Upload server
3. [API.md](./API.md) - API endpoints
4. [CONFIG.md](./CONFIG.md) - Docker setup

### Voor DevOps/Systeembeheerders (45 min)
1. [README.md](./README.md#snelle-start) - Quick start
2. [CONFIG.md](./CONFIG.md) - Alle secties
3. [FILE_SERVER.md](./FILE_SERVER.md) - Deployment

---

## 🔄 Updates & Maintenance

### Documentatie Wordt Bijgewerkt Wanneer:

- ✅ Nieuwe features worden toegevoegd
- ✅ Dependencies worden geupdatet
- ✅ Configuration verandert
- ✅ Bugs worden opgelost

### Laatst Bijgewerkt

- **Datum**: 2026
- **Versie**: 1.0.0
- **Status**: Volledig

---

## 📞 Support & Feedback

### Vragen?

- Lees eerst het relevante document
- Check [FAQ](./USERGUIDE.md#-veelgestelde-vragen)
- Contacteer je IT-beheerder

### Feedback op Documentatie?

- Report issues op GitHub
- Suggesties voor verbetering welkom

---

## 🎯 Korte Samenvattingen

### README.md
Compleet project overzicht met snelle start, structuur, technologie stack en links naar gedetailleerde docs.

### USERGUIDE.md
Praktische stap-voor-stap gids voor eindgebruikers om het dashboard te gebruiken.

### COMPONENTS.md
Uitgebreide beschrijving van alle React componenten en hun interacties.

### FILE_SERVER.md
API documentatie voor de upload server en project data management.

### HOOKS.md
Gedetailleerde gids over custom React hooks en state management.

### CONFIG.md
Configuratie bestanden uitgelegd: package.json, vite, tailwind, docker, etc.

### API.md
API integratie, proxy configuration, request/response examples.

---

**Start je avontuur met het Netwerkscanner Dashboard!** 🚀

---

*Versie 1.0.0 - 2026*

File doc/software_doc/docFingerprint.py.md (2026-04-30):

Hoe container hermaken als je aanpassingen hebt gemaakt.  
`docker compose up -d --build wifi_api `

Hoe ga je in de terminal van de container om individuele programma's te testen.  
` docker exec -it wifi_api /bin/bash`

werkt dit niet, de container is nog niet gestart. gebruik `docker logs wifi_api`

start python programma
`python3 fingerprint.py`

build het volledige project
`docker compose up -d --build`

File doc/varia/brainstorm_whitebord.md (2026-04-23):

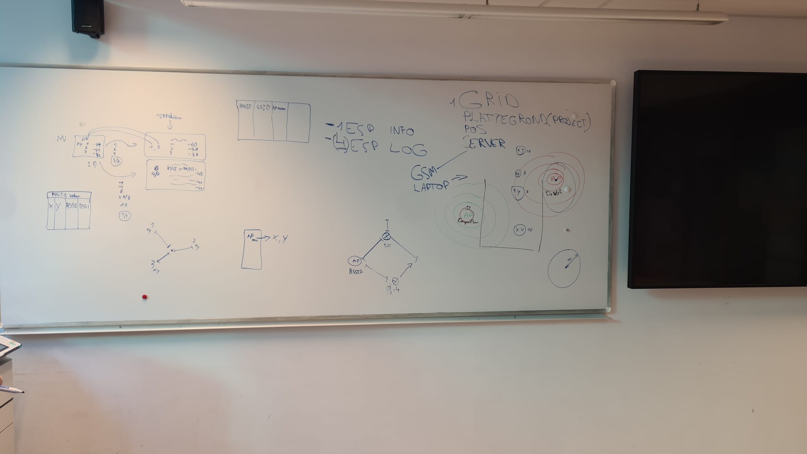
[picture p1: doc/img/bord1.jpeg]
bord1

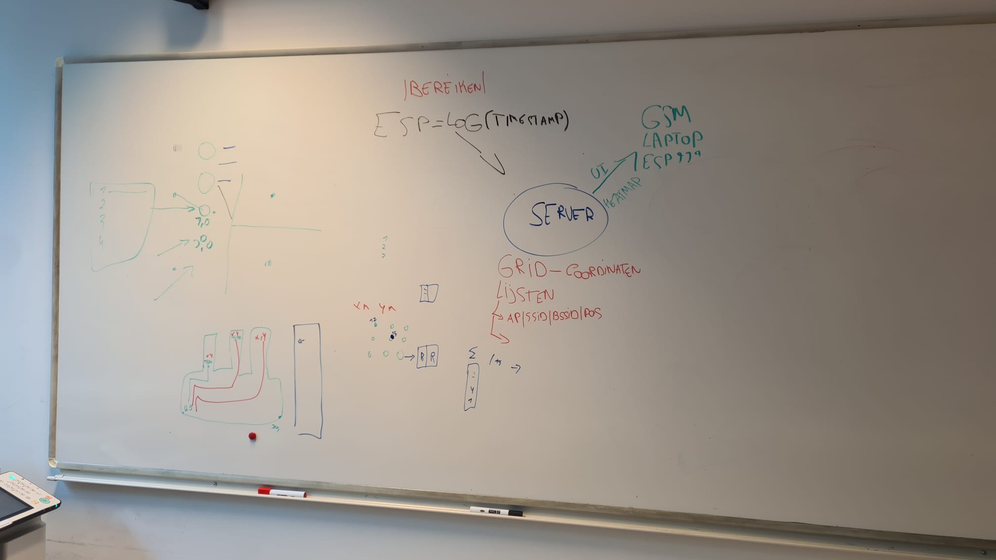
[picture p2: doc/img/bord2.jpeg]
bord2

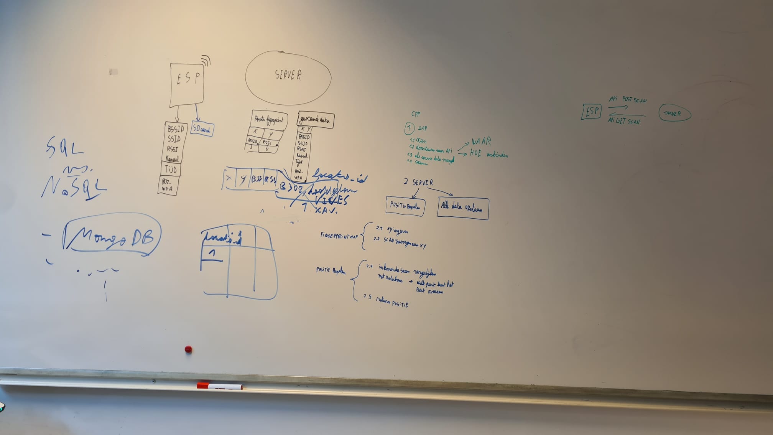
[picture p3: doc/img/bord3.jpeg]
bord3


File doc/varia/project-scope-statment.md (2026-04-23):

# Netwerkscanner – Toegelaten Inventarisatie

Doel:

Het project heeft als doel een read-only netwerkscanner te ontwikkelen die een overzicht geeft van toegelaten netwerkapparaten en basisdiensten, zonder impact op netwerkstabiliteit of beveiliging.

---

## Binnen scope

- Detecteren van actieve hosts via ICMP

- Beperkte TCP-poortscans op vooraf goedgekeurde poorten

- Weergeven van IP-adres, hostname en open poorten

- Manueel starten van scans

- Opslaan van scanresultaten voor documentatie

---

## Buiten scope

- Vulnerability scanning

- Exploit- of penetratietests

- OS-fingerprinting

- UDP-scans

- Automatische of continue scanning

- Scans op niet-goedgekeurde netwerken of toestellen

---

## Beperkingen

- Scanner werkt volledig read-only

- Geen wijzigingen aan systemen of netwerkinfrastructuur

- Resultaten worden enkel intern gebruikt

- GDPR-principes worden gevolgd

---

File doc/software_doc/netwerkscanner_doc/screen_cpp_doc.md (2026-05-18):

# SCREEN

Deze code laat de ESP toe om tekst en vormen op het scherm te tonen.

## Opbouw

De code bestaat uit 3 lagen:

---

## Laag 1 — Communicatie met het scherm

Deze laag verzorgt de directe communicatie met het display.

### Functies
- `LcdCommand()`
- `LcdData()`

Deze functies sturen bytes via SPI naar het scherm.

---

## Laag 2 — Basistekenfuncties

Deze laag bevat de basisfuncties om vormen en pixels te tekenen.

### Functies
- `DrawPixel()`
- `DrawLine()`
- `FillScreen()`
- `DrawRectFilled()`

Met deze functies kunnen lijnen, rechthoeken en volledige schermen getekend of ingevuld worden.

---

## Laag 3 — Tekst en iconen

Deze laag bouwt verder op de tekenfuncties om tekst en iconen weer te geven.

### Functies
- `DrawStringFast()`
- `DrawWifiIcon()`

Deze functies worden gebruikt om tekst en symbolen op een efficiënte manier op het scherm te tonen.

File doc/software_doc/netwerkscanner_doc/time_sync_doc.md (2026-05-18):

# TIME SYNC
Deze code syncronizeerd de tijd op de ESP met de tijd op de server, doordat de ESP geen ingebouwde rtc klok heeft.
De 4 Functies:
- Init(): Zet beide variabelen terug op 0, wordt aangeroepen bij het opstarten.
- Sync(): roept de GetTimeFromServer functie op en slaat die op met het huidige ESP-tijdstip.  esp_timer_get_time() telt het aantal microseconden sinds de ESP opgestart is.
- Get(): Berekent de huidige tijd zonder opnieuw naar de server te gaan. Dit wordt berekent door de servertijd op het moment van het opstarten plus het verstreken seconden sinds de sync.

- GetTimeFromServer(): vraagt de tijd op via HTTP GET naar /time api endpoint op de server en leest de timestamp uit het JSON-antwoord.
  De tijd komt van de OS-tijd van de server. Ze wordt niet rechtstreeks opgevraagd bij een NTP-server. Op deze manier zijn alle ESP’s die verbonden zijn met de server gesynchroniseerd met dezelfde klok, waardoor alles gelijk blijft en er geen conflicten ontstaan wanneer het systeem van tijdszone verandert of overschakelt tussen zomer- en winteruur.

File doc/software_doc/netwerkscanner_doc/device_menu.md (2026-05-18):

# MENU

De netwerkscanner toont een klein menu waarop gekozen kan worden welke soorten netwerken gescand moeten worden.

## Ondersteunde netwerken

- Wifi 2.4 GHz
- Wifi 5 GHz
- Bluetooth
- Debug RTOS (extra informatie voor developers)

Links bovenaan wordt ook weergegeven:
- met welk netwerk het device verbonden is
- de naam van het netwerk
- het IP-adres

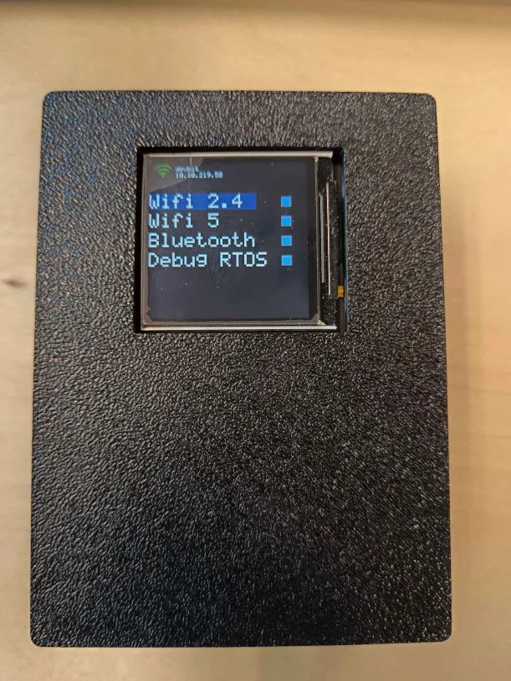
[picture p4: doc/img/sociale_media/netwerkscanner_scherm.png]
Netwerkscanner scherm


---

# FUNCTIES

Het device kan bestuurd worden met de 6 knoppen aan de zijkant, elk met een aparte functie.

## Knoppen

(Van boven naar beneden)

- **Knop 1 = UP**
  - Navigeert omhoog in het menu

- **Knop 2 = DOWN**
  - Navigeert omlaag in het menu

- **Knop 3 = SELECT**
  - Selecteert het netwerk dat gescand moet worden

- **Knop 4 = BACK**

- **Knop 5 = RESET**
  - Voert een harde reset uit van het volledige device

- **Knop 6 = Vrij**
  - Momenteel niet gebruikt

---

# CODE

Doordat de ESP maar 1 processor heeft, kan hij technisch gezien maar 1 taak tegelijk uitvoeren.

Hiervoor wordt gebruik gemaakt van **FreeRTOS**, een klein besturingssysteem dat zeer snel wisselt tussen verschillende taken zodat het lijkt alsof meerdere taken tegelijkertijd uitgevoerd worden.

`xTaskCreate()` wordt gebruikt om een taak aan te maken.

```c
xTaskCreate(
    ScannerTask,    // welke functie
    "ScannerTask",  // naam voor debugging
    4096,           // geheugen (stack) in bytes
    NULL,           // extra parameters
    5,              // prioriteit
    NULL            // handle (optioneel)
);
```

---

# QUEUES

Wanneer verschillende taken dezelfde data willen gebruiken, wordt gebruik gemaakt van **queues**.

Een queue werkt als een wachtrij:
- de eerste data die binnenkomt
- is ook de eerste data die gelezen wordt

Dit voorkomt dat meerdere taken tegelijkertijd dezelfde data gebruiken.

## Gebruikte functies

- `xQueueCreate()`
  - maakt een queue aan

- `xQueueSend()`
  - verstuurt data naar de queue

- `xQueueReceive()`
  - leest data uit de queue

---

# TAKEN

## `MenuTask`

Start het display op en wacht op berichten in de `menuqueue`.

Deze berichten komen van:
- knopinterrupts
- de WiFi-verbindingstaak

### Mogelijke berichten

- `UP`
- `DOWN`
- `SELECT`
- `BACK`
- `EVENT_WIFI_CONNECTED`
- `portMAX_DELAY`

---

## `ScannerTask`

Blijft controleren wat gescand mag worden via `GlobalScanConfig`.

`GlobalScanConfig` bepaalt welke frequentiebanden gebruikt worden in `wifi_scan_config_t`.

### WiFi scanning

Met:

```c
esp_wifi_scan_start()
```

wordt een WiFi-scan gestart.

De code wacht tot de scan volledig klaar is.

Daarna worden de resultaten opgehaald met:

```c
esp_wifi_scan_get_ap_records()
```

De resultaten worden vervolgens in een queue geplaatst voor `JsonBuilderTask`.

---

### Bluetooth scanning

Bluetooth scanning gebeurt via:

```c
StartBleScan(5000)
```

Dit start een scan van 5 seconden.

Via:

```c
ble_gap_event_handler
```

worden gevonden apparaten één voor één in de `BluetoothQueue` geplaatst.

---

## Frequentiebanden

| Scanmodus | Channel bitmap |
|---|---|
| Wifi 2.4 GHz | `0x3ffe` |
| Wifi 5 GHz | `0xfeffffe` |
| Beide | beide bitmaps actief |

---

## `JsonBuilderTask`

Verwerkt de scandata en verstuurt deze naar de server.

De taak gebruikt een **QueueSet**, waardoor tegelijkertijd op meerdere queues gewacht kan worden.

Zodra data beschikbaar is in:
- `WiFiQueue`
- `BluetoothQueue`

wordt de QueueSet actief.

### Werking

- WiFi-data wordt verdeeld in blokken van 10 netwerken per HTTP POST
- daarna wordt het gebruikte geheugen opnieuw vrijgemaakt

---

# KNOPPENSYSTEEM

Wanneer een knop ingedrukt wordt, verandert de spanning en ontstaat een interrupt.

Een knop "stuitert" echter kort bij het indrukken, waardoor meerdere signalen ontstaan terwijl slechts één input gewenst is.

Hiervoor wordt gebruik gemaakt van **debouncing**.

```c
if (now - lastIsrTimeUp < 50000) {  // 50ms in microseconden
    return;  // negeer dit signaal
}
```

Met debouncing worden alle signalen binnen de eerste 50 ms genegeerd zodat slechts één input geregistreerd wordt.

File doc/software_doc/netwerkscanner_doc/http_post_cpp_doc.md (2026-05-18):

# HTTP POST

Deze code verstuurt JSON-data naar de server en ontvangt de berekende locatie terug.

## Functies

---

### `SendJsonPost()`

Verstuurt de JSON-data naar de server.

### Returnwaarden
- `0` → succesvol verzonden
- `1` → fout bij verzenden

---

### `_http_event_handler()`

Wanneer de server antwoordt, wordt deze functie automatisch aangeroepen.

De server stuurt de berekende locatie terug als JSON.  
`_http_event_handler()` haalt deze informatie uit het antwoord en slaat ze op in `LocationBasket`.

Daarna gebruikt `MenuTask` deze informatie via `EVENT_HANDLER`, wat een bericht naar `MenuTask` verstuurt.

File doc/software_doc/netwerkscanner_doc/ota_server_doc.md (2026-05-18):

# OTA SERVER

Via de OTA server kunnen we nieuwe software versturen naar de ESP via WiFi, zonder het gebruik van kabels.

Op de webpagina kies je een `.bin` bestand en de ESP installeert zichzelf opnieuw.  
Via de OTA server verloopt het uploaden sneller en eenvoudiger.

## Functies

---

### `UploadGetHandler()`

Wanneer je surft naar:

```text
http://10.10.219.58/
```

ontvangt de ESP het verzoek en stuurt het `uploadHTML` terug, wat de webpagina bevat voor het uploaden van firmware.

---

### `UploadPostHandler()`

Deze functie ontvangt en installeert het `.bin` bestand.

Bij het uploaden van een bestand via een HTML-formulier stuurt de browser extra tekstinformatie mee.  
De ESP verwacht echter alleen firmwarecode, waardoor dit anders een crash zou veroorzaken.

ESP32 firmwarebestanden beginnen altijd met de byte:

```text
0xE9
```

De functie negeert alle extra informatie vóór deze byte en installeert daarna direct de echte firmwarecode.

---

### `OtaWebserverTask()`

Start de webserver en registreert de benodigde routes.

### Routes

- `/` (`GET`)
  - toont de uploadpagina

- `/update` (`POST`)
  - ontvangt en installeert het `.bin` bestand

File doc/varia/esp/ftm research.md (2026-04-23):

# Fine Timing Measurement (FTM) in WiFi

FTM is een techniek gebruikt in WiFi om **heel nauwkeurig de afstand** tussen twee apparaten te meten. Het is vooral handig voor **indoor positioning** en **precisie-locatiebepaling**.

---

## 1. Basisprincipe

FTM werkt via **Round-Trip Time (RTT)**:

1. Device A stuurt een FTM-request naar Device B.
2. Device B stuurt een FTM-response terug.
3. Device A meet de tijd tussen het versturen van de request en het ontvangen van de response.

De afstand wordt berekend met de formule:

\[
\text{Afstand} = \frac{\text{RTT} \times c}{2}
\]

Waarbij:

- \( \text{RTT} \) = Round-Trip Time (tijd in seconden)
- \( c \) = snelheid van het licht (~\(3 \times 10^8\) m/s)
- Deling door 2 omdat het signaal heen en terug gaat

---

## 2. Vereisten voor FTM

- Beide apparaten moeten **802.11mc (WiFi RTT)** ondersteunen.
- Het netwerk kan op **2.4 GHz** of **5 GHz** werken, maar 5 GHz geeft betere nauwkeurigheid.
- FTM kan gebruikt worden met **APs (Access Points)** en **clients** die FTM ondersteunen.

---

## 3. Processtappen

1. **Initiatie:** Client stuurt FTM Request naar AP.
2. **Antwoord:** AP stuurt FTM Response.
3. **Tijdmeting:** Client meet exacte tijd van heen en terug.
4. **Berekening:** Client gebruikt RTT voor afstandsberekening.
5. **Eventueel averaging:** Meerdere RTT metingen om fouten te verminderen.

---

## 4. Nauwkeurigheid

- Typisch: **~1 tot 2 meter** foutmarge
- Door **meerdere metingen** te nemen kan nauwkeurigheid verbeterd worden.
- Obstakels en reflecties (multipath) kunnen de meting beïnvloeden.

---

## 5. Toepassingen

- Indoor navigatie (zoals in winkels of magazijnen)
- Robotica en drones
- Asset tracking
- Smart home toepassingen

---

## 6. Voordelen

- Hoge precisie in vergelijking met RSSI-only methoden.
- Werkt met bestaande WiFi-netwerken.
- Kan real-time locatie-updates geven.

---

## 7. Beperkingen

- Vereist 802.11mc compatibele hardware.
- Nauwkeurigheid wordt beïnvloed door muren, objecten en reflecties.
- Niet altijd beschikbaar op oudere apparaten.

---

## 8. Voorbeeldformule

Stel RTT = 20 nanoseconden (ns):

\[
\text{Afstand} = \frac{20 \times 10^{-9} \times 3 \times 10^8}{2} = 3 \text{ meter}
\]

---

FTM maakt het dus mogelijk om **exact te meten hoe ver apparaten van elkaar verwijderd zijn**, veel nauwkeuriger dan enkel met signaalsterkte (RSSI).

```mermaid
flowchart LR
    A["1. Client / Device A"] -->|2. FTM Request| B["2. Access Point / Device B"]
    B -->|3. FTM Response| A
    A --> C["4. Meet Round-Trip Time (RTT)"]
    C --> D["5. Bereken Afstand: Afstand = (RTT * c) / 2"]
    D --> E["6. Nauwkeurige locatie of tracking"]
    D -->|Herhaal meerdere metingen| C
```

code snippet:

```c++
#include "esp_wifi.h"
#include "esp_event.h"
#include "esp_log.h"
#include "nvs_flash.h"

static const char* TAG = "FTM";

// SSID van het AP dat FTM ondersteunt
#define TARGET_SSID "YourFTMAP"

// Callback functie voor RTT events
static void wifi_rtt_event_handler(void* arg, esp_event_base_t event_base,
                                   int32_t event_id, void* event_data) {
    if (event_id == WIFI_EVENT_RTT_REPORT) {
        // RTT-rapport ontvangen
        wifi_rtt_report_t* report = (wifi_rtt_report_t*)event_data;
        if (report->status == WIFI_RTT_STATUS_SUCCESS) {
            // RTT in seconden (van nanoseconden)
            float rtt_sec = report->rtt / 1e9;
            // Afstand berekenen: afstand = (RTT * snelheid van licht) / 2
            float afstand = (rtt_sec * 3e8) / 2;
            ESP_LOGI(TAG, "RTT: %f ns, Afstand: %.2f m", report->rtt, afstand);
        } else {
            // Als FTM meting mislukt
            ESP_LOGW(TAG, "FTM mislukte meting, status=%d", report->status);
        }
    }
}

void app_main() {
    // 1️⃣ NVS initialisatie nodig voor WiFi opslag
    nvs_flash_init();

    // 2️⃣ TCP/IP stack initialiseren
    tcpip_adapter_init();

    // 3️⃣ Event loop aanmaken zodat WiFi events kunnen worden afgehandeld
    ESP_ERROR_CHECK(esp_event_loop_create_default());

    // 4️⃣ WiFi initialisatie
    wifi_init_config_t cfg = WIFI_INIT_CONFIG_DEFAULT();
    ESP_ERROR_CHECK(esp_wifi_init(&cfg));

    // 5️⃣ ESP32 als Station (client) instellen
    ESP_ERROR_CHECK(esp_wifi_set_mode(WIFI_MODE_STA));

    // 6️⃣ WiFi starten
    ESP_ERROR_CHECK(esp_wifi_start());

    // 7️⃣ Callback registreren voor RTT events
    ESP_ERROR_CHECK(esp_event_handler_register(
        WIFI_EVENT, WIFI_EVENT_RTT_REPORT, &wifi_rtt_event_handler, NULL));

    // 8️⃣ RTT configuratie
    wifi_rtt_config_t rtt_cfg = {0};
    strcpy((char*)rtt_cfg.ssid, TARGET_SSID);  // doel-AP
    rtt_cfg.rtt_num_measurements = 8;          // aantal RTT metingen
    rtt_cfg.rtt_interval_ms = 100;             // interval tussen metingen

    // 9️⃣ Start RTT meting
    ESP_ERROR_CHECK(esp_wifi_start_rtt(&rtt_cfg));

    ESP_LOGI(TAG, "FTM meting gestart naar %s", TARGET_SSID);
}
```

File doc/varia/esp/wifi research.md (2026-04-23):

# WiFi Research

## WiFi Modes

| Mode | Beschrijving |
| --- | --- |
| `Station` | Verbindt met een bestaand WiFi netwerk |
| `Access Point` | Maakt een eigen WiFi netwerk aan |
| `Station + AP` | Kan beide tegelijk |

## Veelgebruikte WiFi Commando's (ESP)

```cpp
WiFi.begin(ssid, password);        // Verbindt met netwerk
WiFi.softAP(ssid, password);       // Start access point
WiFi.status();                     // Controleert status
WiFi.disconnect();                 // Verbreekt verbinding
```

## WiFi Security Types

| Type | Omschrijving |
| :---: | :---: |
| `WEP` | Verouderd, onveilig |
| `WPA` | Verbeterd, matig |
| `WPA2` | Modern, veilig |
| `WPA3` | Nieuwste, zeer veilig |

## Veelvoorkomende Problemen

| Probleem | Mogelijke Oplossing |
| :---: | :---: |
| Kan niet verbinden | Controleer SSID en wachtwoord |
| Slechte signaalsterkte  | Verplaats dichter bij router/AP |
| IP-adres niet verkregen | Controleer DHCP instellingen |

## WiFi Scan Voorbeeld (ESP)

```cpp
int n = WiFi.scanNetworks();
for (int i = 0; i < n; ++i) {
  Serial.print(WiFi.SSID(i));
  Serial.print(" (");
  Serial.print(WiFi.RSSI(i));
  Serial.println(" dBm)");
}
```

## Handige Links

- [ESP32 WiFi Library](https://docs.espressif.com/projects/esp-idf/en/latest/esp32/api-reference/network/esp_wifi.html)
- [Arduino WiFi Library](https://www.arduino.cc/en/Reference/WiFi)

---

# 1. Inleiding

## 1.1 Doelstelling

Het doel van dit onderzoek is het analyseren van WiFi volgens de IEEE 802.11-standaard.  
Focus ligt op **fysische laag (PHY) en MAC-laag**, inclusief netwerkdetectie, authenticatie, datatransmissie en foutcontrole.

## 1.2 Onderzoeksvragen

- Hoe werkt WiFi volgens IEEE 802.11?
- Hoe verloopt netwerkdetectie?
- Hoe gebeurt authenticatie en associatie?
- Hoe wordt mediumtoegang geregeld?
- Hoe wordt betrouwbaarheid verzekerd?

```mermaid
sequenceDiagram
    participant Client
    participant AccessPoint

    Note over AccessPoint: Beacon (±100 ms)

    Client->>AccessPoint: Probe Request
    AccessPoint->>Client: Probe Response

    Client->>AccessPoint: Authentication Request
    AccessPoint->>Client: Authentication Response

    Client->>AccessPoint: Association Request
    AccessPoint->>Client: Association Response

    Note over Client,AccessPoint: WPA2 4-Way Handshake

    Client->>AccessPoint: Data Frame
    AccessPoint->>Client: ACK

    Client->>AccessPoint: Volgend Frame
    AccessPoint->>Client: ACK
```

---

# 2. Theoretisch Kader

## 2.1 IEEE 802.11

WiFi is gebaseerd op IEEE 802.11 en opereert op:

- **OSI Layer 1**: Physical Layer (PHY)  
- **OSI Layer 2**: Medium Access Control (MAC)  

Kenmerken:

- Half-duplex communicatie
- Gedeeld transmissiemedium
- Collision Avoidance mechanisme

| Naam | Uitleg |
| --- | --- |
| `IEEE` | Institute of Electrical and Electronics Engineers |
| `802`  | Werkgroep voor netwerken |
| `.11`  | Standaard voor draadloze netwerken |

### Versies van 802.11

| Standaard | Jaar  | Frequentieband | Max. Snelheid |
| :---: | :---: | :---: | :---: |
|  802.11b  | 1999  | 2.4 GHz | 11 Mbps |
|  802.11a  | 1999  | 5 GHz | 54 Mbps |
|  802.11g  | 2003  | 2.4 GHz | 54 Mbps |
|  802.11n  | 2009  | 2.4/5 GHz | 600 Mbps |
| 802.11ac  | 2013  | 5 GHz | 1.3 Gbps |
| 802.11ax  | 2019  |  2.4/5/6 GHz | 9.6 Gbps |

---

## 2.2 Fysische Laag (PHY)

### Frequentiebanden

| Band | Voordelen | Nadelen |
| :-----: | :---: | :---: |
| 2.4 GHz | Groot bereik, beter door muren | Drukker, lagere snelheid |
| 5 GHz | Hogere snelheid, minder interferentie | Korter bereik, slechtere penetratie |
| 6 GHz | Zeer hoge snelheid, weinig interferentie | Zeer kort bereik |

Max zendvermogen EU/BE:

| Band | Frequentie | Max EIRP | Opmerking |
| :-----: | :---: | :---: | :---: |
| 2.4 GHz | 2400-2483.5 MHz | 20 dBm | Standaard |
| 5 GHz | 5150-5350 MHz | 23 dBm | Indoor |
| 5 GHz | 5470-5725 MHz | 30 dBm | DFS, outdoor |
| 5 GHz | 5725-5875 MHz | 14 dBm | Enkel outdoor |
| 6 GHz | 5945-7125 MHz | 30 dBm | DFS, indoor/outdoor |

- 2.4 GHz: 14 kanalen (1,6,11 niet-overlappend)  
- 5 GHz: 24 kanalen, breedte 20/40/80/160 MHz  
- 6 GHz: 59 kanalen, zeer weinig congestie  

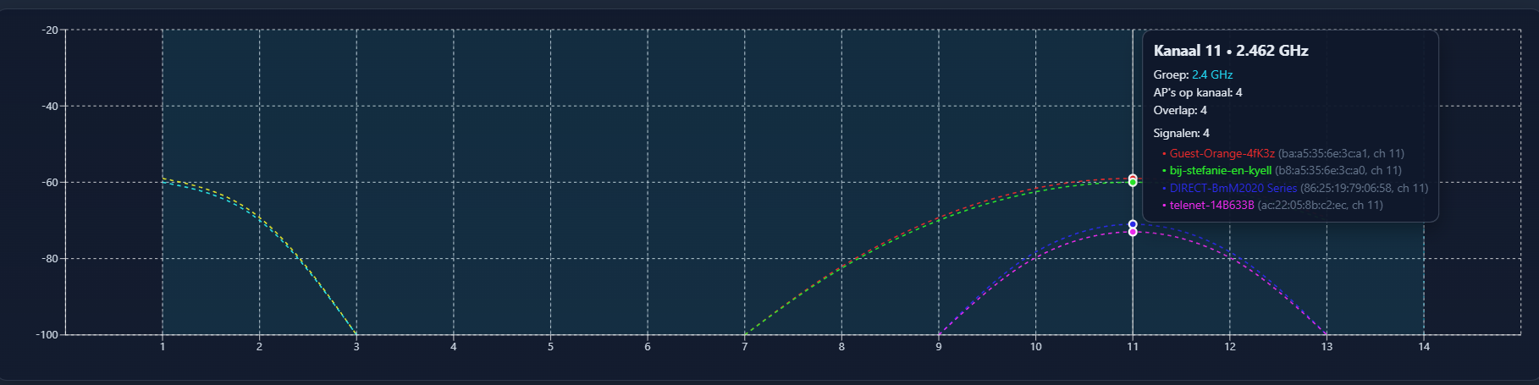
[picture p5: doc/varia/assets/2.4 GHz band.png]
2.4 GHz
  
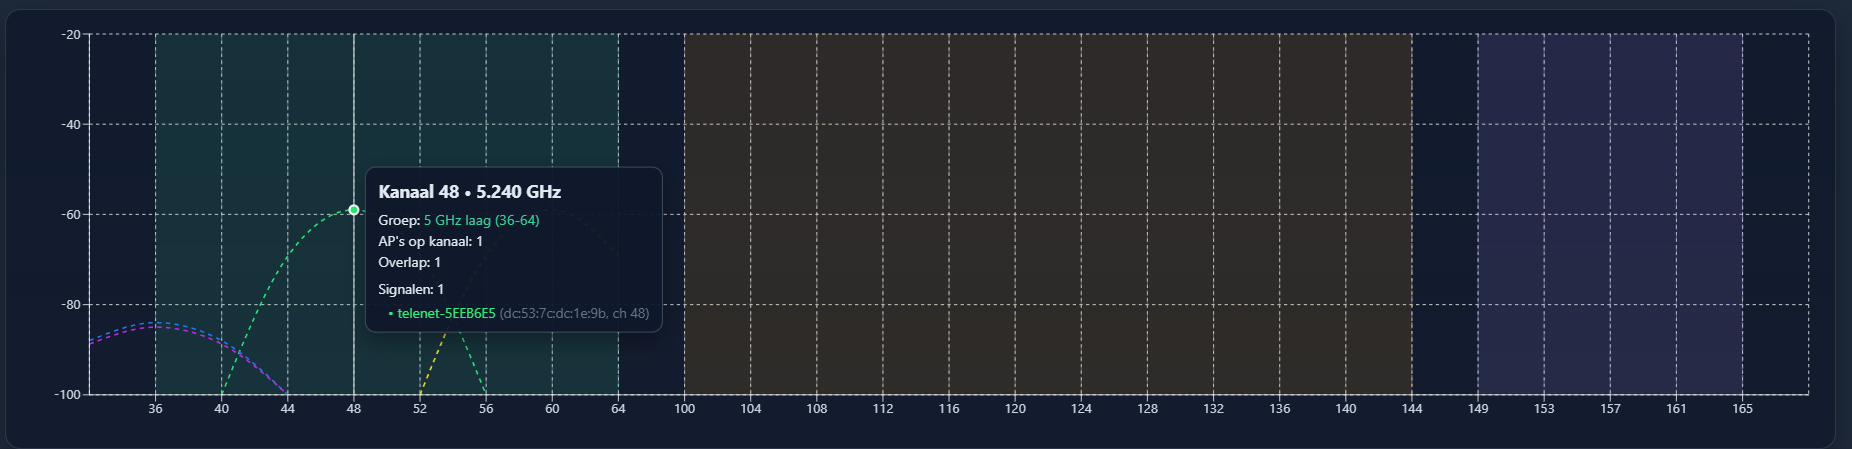
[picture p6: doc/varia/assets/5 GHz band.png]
5 GHz
  
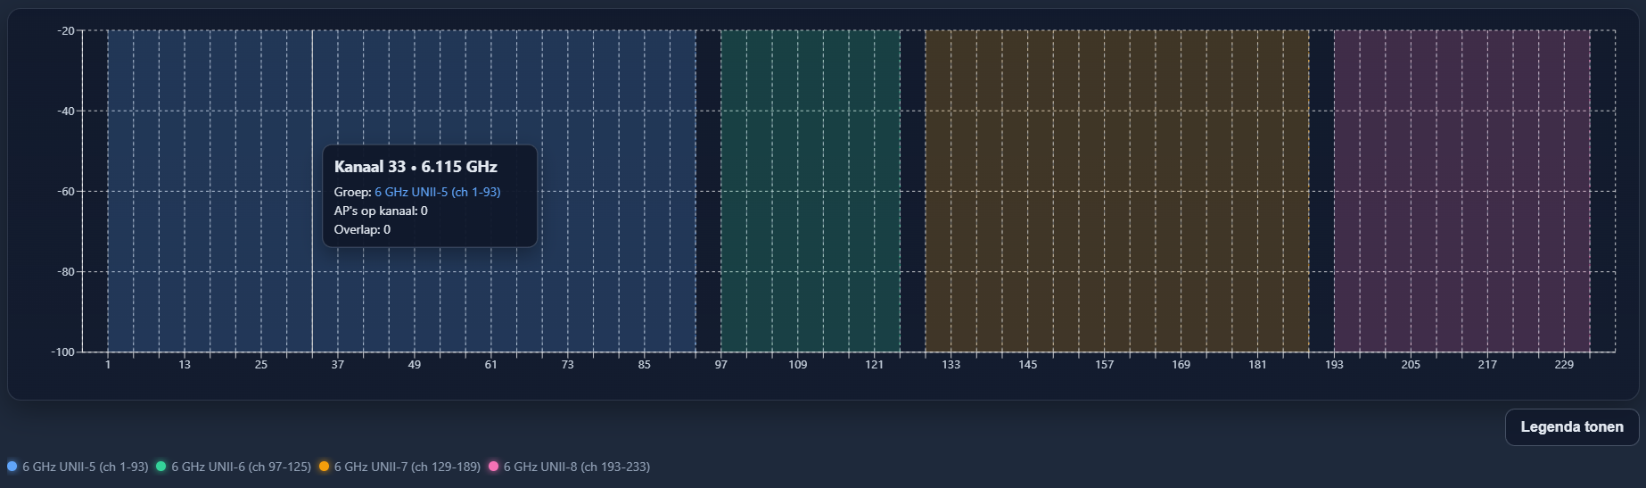
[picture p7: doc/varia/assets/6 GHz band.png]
6 GHz


### Modulatie

| Modulatie | Bits per symbool | Beschrijving |
| :---: | :---: | :---: |
| BPSK | 1 | Robuust, lage snelheid |
| QPSK | 2 | Robuust, lage snelheid |
| 16-QAM | 4 | Middelmatig, hogere snelheid |
| 64-QAM | 6 | Hogere snelheid |
| 256-QAM | 8 | Zeer hoge snelheid |
| 1024-QAM  | 10 | Zeer hoge snelheid |

**OFDM**: verdeelt spectrum in subcarriers (parallelle snelwegen).  
**QAM**: amplitude + fase modulatie, meer bits per symbool, hogere SNR nodig.

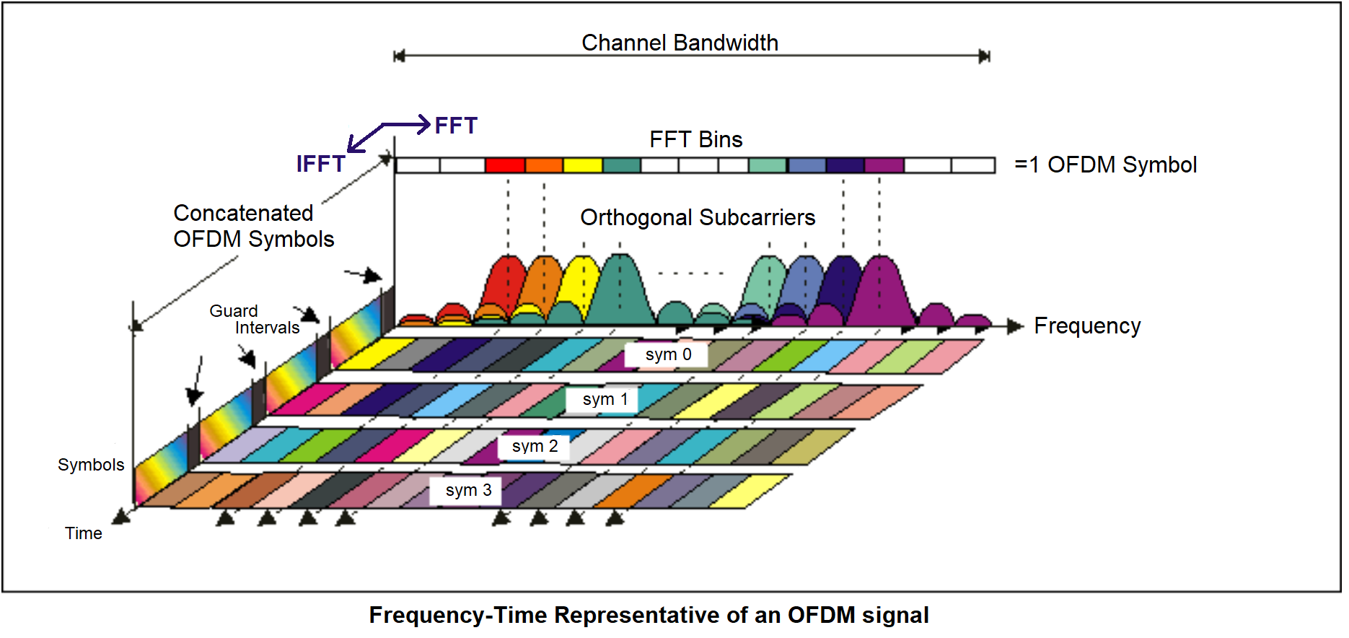
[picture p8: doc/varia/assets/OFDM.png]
OFDM
  
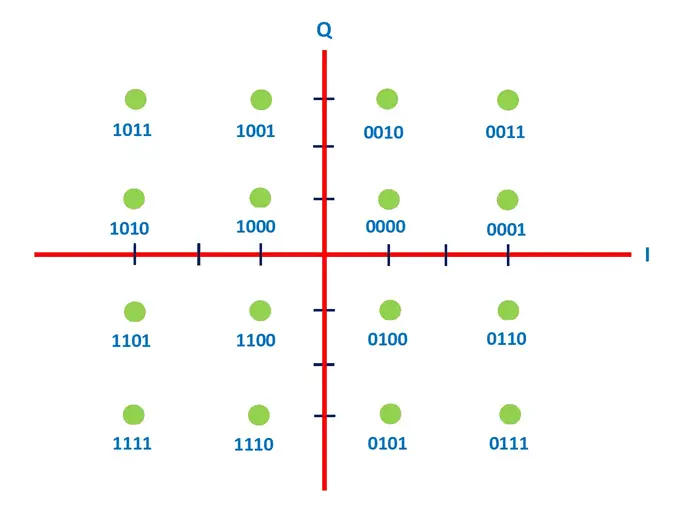
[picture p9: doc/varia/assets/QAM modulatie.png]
QAM


### Bitrate

- `Bitrate = Symbol Rate x Bits per Symbool`  
- Hogere modulatie → hogere snelheid, maar gevoeliger voor ruis  
- SNR > 34 dBmV nodig voor 256-QAM bij Telenet downstream

---

## 2.3 MAC Laag

### Scanning

- **Passive Scan**: Luistert naar beacon frames (energiezuinig)  
- **Active Scan**: Stuurt probe requests uit (sneller)  

### Authenticatie

| Type | Kenmerken |
| :---: | :---: |
| Open System | Snel, geen beveiliging |
|  WPA2/WPA3 Personal  | PSK, thuisnetwerken, betere beveiliging |
| WPA2/WPA3 Enterprise | RADIUS-server, unieke gebruikers, sterkste beveiliging |

### Associatie

- Association Request → info over apparaat en gewenste netwerkconfiguratie  
- Association Response → statuscode, toegewezen AID, ondersteunde snelheden  
- WPA2 4-Way Handshake voor veilige verbinding

### Datatransmissie

- **CSMA/CA**: Carrier Sense, collision avoidance  
- **Backoff Mechanisme**: willekeurige wachttijd bij bezet medium  
- **ACK**: bevestiging van succesvolle ontvangst

### Frame Types

| Type | Beschrijving |
| :---: | :---: |
| Management Frames | Beacon, Probe, Authentication, Association  |
|  Control Frames | ACK, RTS, CTS, NACK |
| Data Frames | Eigenlijke payload, MAC-adressen, encryptie |

### Foutdetectie

- **CRC**: detecteert fouten  
- **Hertransmissie**: opnieuw verzenden bij fout of geen ACK

---

## 4 Modulatie Uitleg – OFDM & QAM

### OFDM (Orthogonal Frequency Division Multiplexing)

`OFDM` verdeelt het beschikbare spectrum in meerdere subcarriers, elk gemoduleerd met een lagere snelheid.

- Voordelen: hoge efficiëntie, robuust tegen multipath fading, geschikt voor hoge snelheden.  
- Nadelen: complex, gevoelig voor frequentie-offsets.  
- Wordt gebruikt in standaarden: `802.11a/g/n/ac/ax`.  
- Elke subcarrier kan gemoduleerd worden met `BPSK`, `QPSK`, `16-QAM`, `64-QAM`, `256-QAM` of `1024-QAM`.  

**Werking van OFDM:**

1. Data wordt opgesplitst in meerdere parallelle datastromen.  
2. Elke datastroom wordt gemoduleerd met een specifieke modulatie (`BPSK`, `QPSK`, `16-QAM`, etc.).  
3. De gemoduleerde stromen worden toegewezen aan specifieke subcarriers.  
4. Subcarriers worden gecombineerd en verzonden.  
5. Ontvanger scheidt, demoduleert en reconstrueert de oorspronkelijke data.  
6. Guard interval vermindert intersymbol interference (ISI).  

OFDM  

---

### QAM (Quadrature Amplitude Modulation)

`QAM` combineert amplitude- en fase-modulatie om meerdere bits per symbool te coderen.

| Modulatie | Bits per symbool | Symbolen | Toepassing |
| :---: | :---: | :---: | :---: |
| BPSK | 1 | 2 | lage snelheid, lange afstand |
| QPSK | 2 | 4 | lage/moderate snelheid |
| 16-QAM | 4 | 16 | gemiddelde snelheid |
| 64-QAM | 6 | 64 | hoge snelheid |
| 256-QAM | 8 | 256 | zeer hoge snelheid |
| 1024-QAM  | 10 | 1024 | ultra hoge snelheid |

**Werking van QAM:**

1. Bits worden gegroepeerd volgens de modulatie.  
2. Elk blok bits wordt toegewezen aan een symbool in de constellatie.  
3. Symbool wordt omgezet in een analoog signaal (fase en amplitude).  
4. Ontvanger demoduleert om de oorspronkelijke bits terug te krijgen.  

💡 Hoe hoger de modulatie, hoe meer bits per symbool, maar hoe gevoeliger voor ruis en interferentie.  

- In WiFi wordt QAM vaak gecombineerd met OFDM, waarbij elke subcarrier gemoduleerd wordt afhankelijk van signaalsterkte en kwaliteit.  
- Bijvoorbeeld bij Telenet: `256-QAM downstream` (van netwerk naar gebruiker), `64-QAM upstream` (van gebruiker naar netwerk).  
- `SNR` (Signal-to-Noise Ratio) bepaalt de maximale modulatie: hogere SNR → hogere modulatie → hogere snelheid.

QAM

---

# 3 Overzicht WiFi – PHY & MAC

```mermaid
flowchart TD
    %% Stijlen
    classDef phy fill:#e0f7fa,stroke:#006064,stroke-width:2px;
    classDef mac fill:#fff3e0,stroke:#e65100,stroke-width:2px;
    classDef scan fill:#ffecb3,stroke:#ff6f00,stroke-width:2px;
    classDef auth fill:#c8e6c9,stroke:#2e7d32,stroke-width:2px;
    classDef assoc fill:#d1c4e9,stroke:#512da8,stroke-width:2px;
    classDef data fill:#ffcdd2,stroke:#b71c1c,stroke-width:2px;
    classDef frame fill:#b3e5fc,stroke:#0277bd,stroke-width:2px;
    classDef crc fill:#f0f4c3,stroke:#827717,stroke-width:2px;

    %% Hoofdstructuur
    A[WiFi Netwerk] --> B[IEEE 802.11 Standaard]

    B --> C[Fysische Laag PHY]:::phy
    B --> D[MAC Laag]:::mac

    %% PHY
    C --> C1[Frequentiebanden]:::phy
    C1 --> C11[2.4 GHz]:::phy
    C1 --> C12[5 GHz]:::phy
    C1 --> C13[6 GHz]:::phy

    C --> C2[Modulatie]:::phy
    C2 --> C21[OFDM]:::phy
    C2 --> C22[QAM]:::phy

    C --> C3[Bitrate]:::phy
    C3 --> C31[Symbol Rate]:::phy
    C3 --> C32[Bits per Symbool]:::phy

    %% MAC
    D --> D1[Scanning]:::scan
    D1 --> D11[Passive Scan]:::scan
    D1 --> D12[Active Scan]:::scan

    D --> D2[Authenticatie]:::auth
    D2 --> D21[Open System]:::auth
    D2 --> D22[WPA2 / WPA3]:::auth

    D --> D3[Associatie]:::assoc
    D3 --> D31[Association Request]:::assoc
    D3 --> D32[Association Response]:::assoc

    D --> D4[Datatransmissie]:::data
    D4 --> D41[CSMA/CA]:::data
    D4 --> D42[Backoff Mechanisme]:::data
    D4 --> D43[ACK Bevestiging]:::data

    D --> D5[Frame Types]:::frame
    D5 --> D51[Management Frames]:::frame
    D5 --> D52[Control Frames]:::frame
    D5 --> D53[Data Frames]:::frame

    D --> D6[Foutdetectie]:::crc
    D6 --> D61[CRC Controle]:::crc
    D6 --> D62[Hertransmissie]:::crc
```

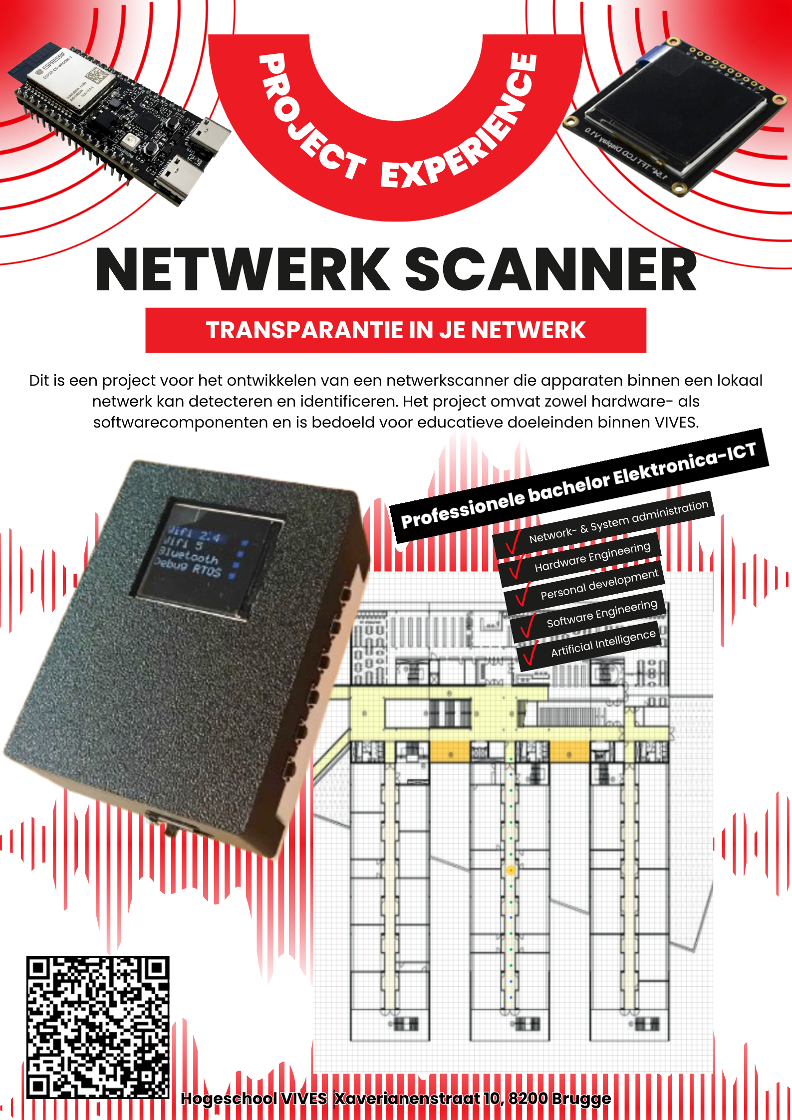
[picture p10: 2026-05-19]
doc/poster/FinalePosterPX4.png

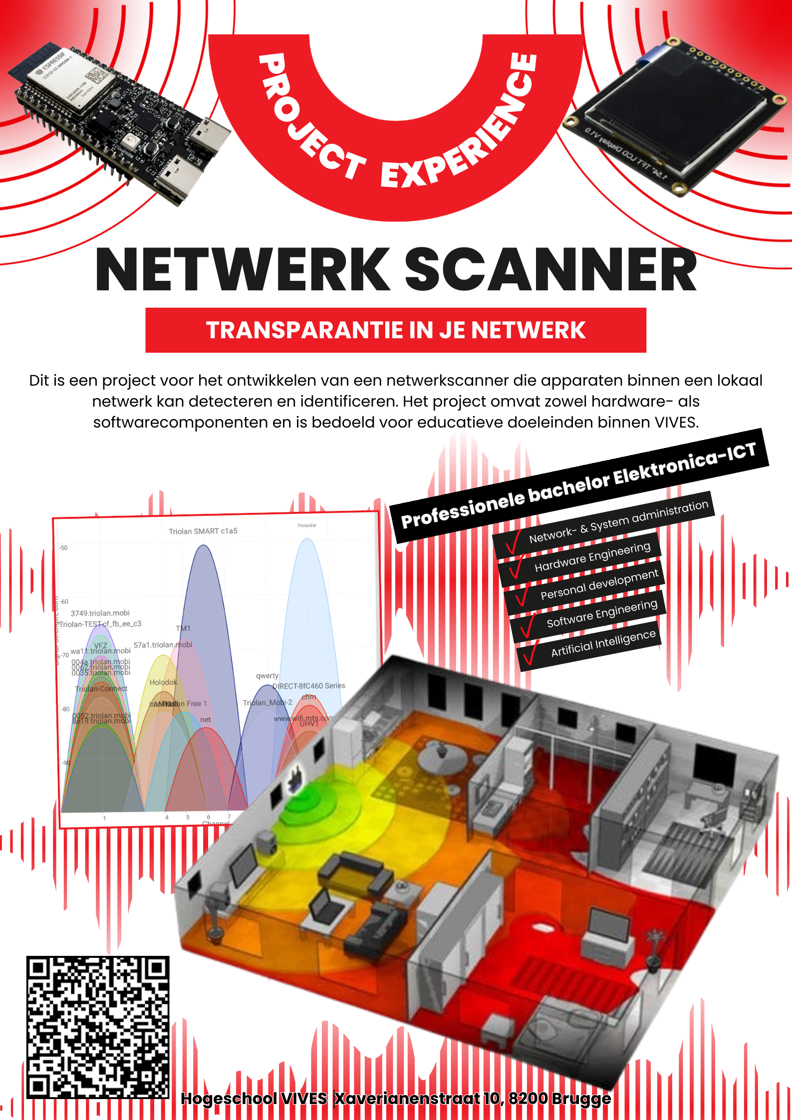
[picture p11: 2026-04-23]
doc/poster/Copy of VIVES sjabloon2.png

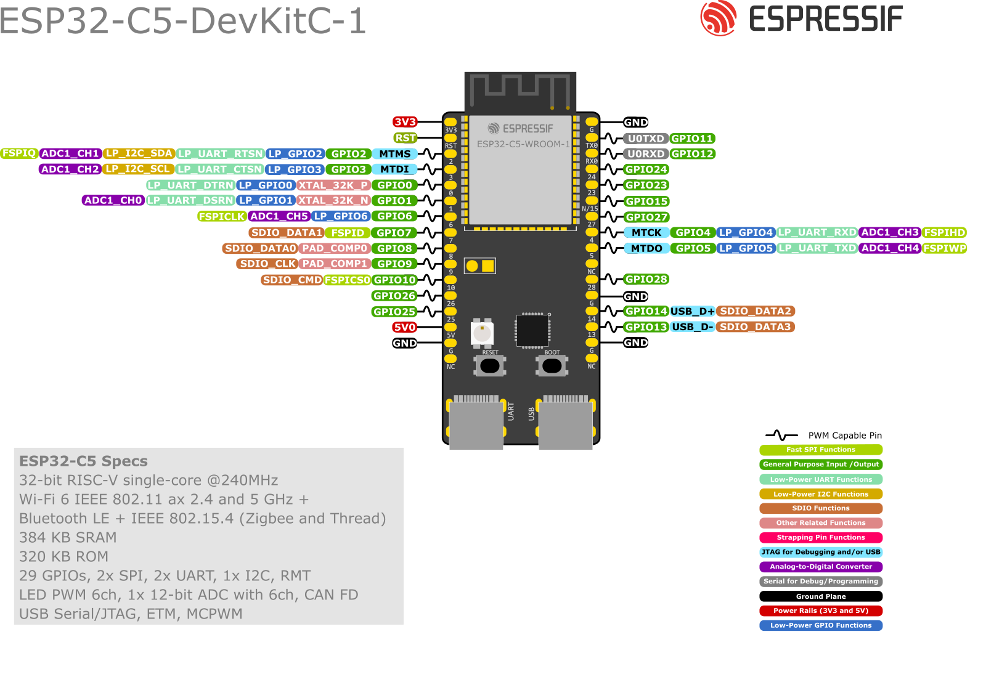
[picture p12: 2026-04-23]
doc/varia/esp/ESP32-C5-DevKitC-1 pinout.png

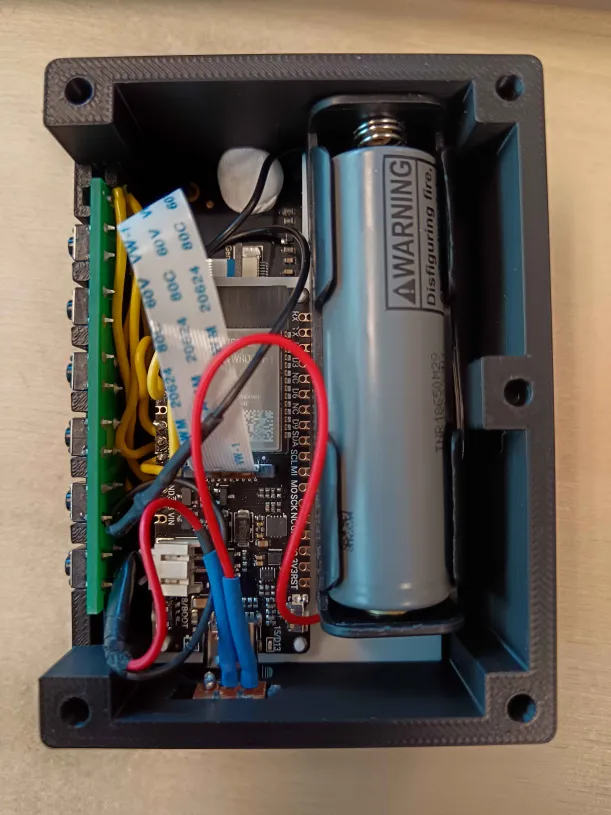
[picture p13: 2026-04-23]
doc/img/sociale_media/binnenkant_netwerkscanner.png

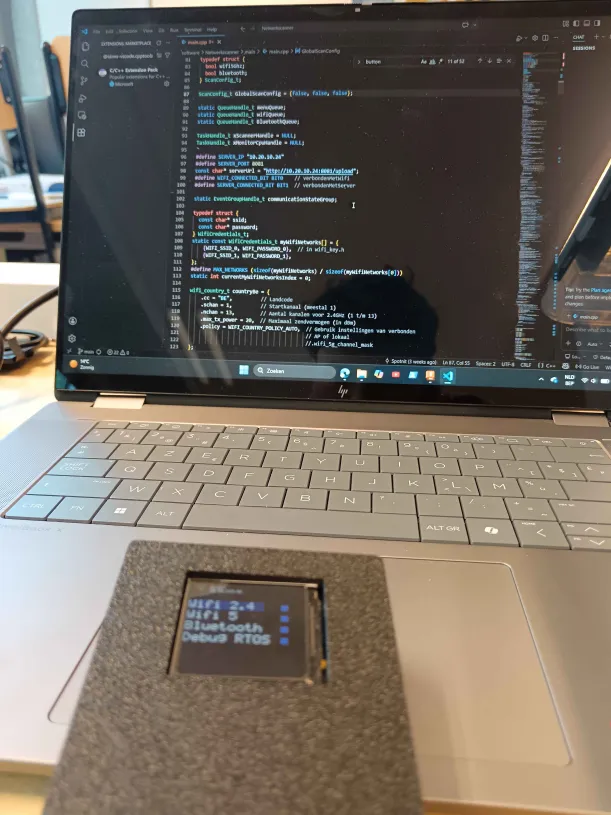
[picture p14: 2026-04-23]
doc/img/sociale_media/code_en_netwerkscanner.png

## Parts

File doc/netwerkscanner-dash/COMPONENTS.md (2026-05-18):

# React Componenten - Gedetailleerde Gids

## 📑 Inhoudsopgave
1. [App.jsx](#appjsx)
2. [Pages](#pages)
3. [Components](#components)
4. [Hooks](#hooks)

---

## App.jsx

**Locatie**: `src/App.jsx`

### Doel
Hoofdtoepassing met:
- Tab-navigatie (Dashboard / Gebouwen)
- Gebouw selectie management
- Loading state handling
- Responsive layout met sidebar

### Structuur

```jsx
export default function App()
```

**Props**: Geen (root component)

**State**:
```javascript
activeTab          // 'dashboard' of 'gebouwen'
selectedBuildingId // ID van geselecteerd gebouw of null
buildings          // Array van alle gebouwen
isLoaded           // Boolean: data geladen?
```

**Key Features**:
- Laadscherm met spinner terwijl database initialiseert
- Adaptive navigation (sidebar verborgen op mobiel)
- Dynamische pagina rendering op basis van activeTab
- Building detail view met terug-navigatie

### Component Hierarchie
```
App
├── Sidebar (links menu)
├── Dashboard (tab)
├── Buildings (tab)
└── BuildingDetail (sub-view)
```

---

## Pages

### Dashboard.jsx
**Locatie**: `src/pages/Dashboard.jsx`

**Doel**: Startpagina met overzichten en statistieken

**Props**:
- `buildings` (array) - Alle beschikbare gebouwen

**Weergave**:
- Statistieken (aantal gebouwen, verdiepingen, etc.)
- Recente activiteiten
- Snelle koppelingen naar functies

---

### Buildings.jsx
**Locatie**: `src/pages/Buildings.jsx`

**Doel**: Beheer van gebouwen (CRUD operaties)

**Props**:
```javascript
buildings        // Array van gebouwen
onAddBuilding    // Callback: (buildingData) => void
onDeleteBuilding // Callback: (buildingId) => void
onSelectBuilding // Callback: (building) => void
```

**Functionaliteit**:
- Lijst alle gebouwen op
- Voeg nieuw gebouw toe (formulier)
- Verwijder gebouw (met bevestiging)
- Selecteer gebouw voor detail view

**UI Elementen**:
- Gebouw kaarten met preview
- "Nieuw Gebouw" knop
- Verwijder knop per gebouw

---

### BuildingDetail.jsx
**Locatie**: `src/pages/BuildingDetail.jsx`

**Doel**: Detail weergave van één gebouw met verdiepingen

**Props**:
```javascript
building        // Object met gebouwgegevens
onBack          // Callback: () => void (terug naar list)
onAddFloor      // Callback: (buildingId, floorData) => void
onDeleteFloor   // Callback: (buildingId, floorId) => void
```

**Functionaliteit**:
- Toon gebouwdetails
- Beheer verdiepingen (toevoegen/verwijderen)
- Toon verdiepingskaart met plattegrond
- Plaats en beheer access points
- Visualiseer RSSI-gegevens

**Subcomponenten**:
- `FloorSelector` - Verdiepingkeuze
- `FloorConfig` - Verdiepingsconfiguratie
- `AccessPointList` - Lijst van access points
- `AccessPointDrawer` - Toevoegen/bewerken punten

---

## Components

### Sidebar.jsx
**Locatie**: `src/components/Sidebar.jsx`

**Doel**: Navigatie menu met gebouwen lijst

**Props**:
```javascript
buildings       // Array van gebouwen
activeTab       // Huidige actieve tab
onTabChange     // Callback: (tabName) => void
onSelectBuilding // Callback: (buildingId) => void
```

**Functionaliteit**:
- Toon navigatie tabs (Dashboard, Gebouwen)
- Snelle links naar alle gebouwen
- Highlight huiding tab
- Responsive (verborgen op kleine schermen)

---

### FloorSelector.jsx
**Locatie**: `src/components/FloorSelector.jsx`

**Doel**: Selectie van verdieping in een gebouw

**Props**:
```javascript
building      // Gebouw object met verdiepingen
onFloorSelect // Callback: (floorId) => void
selectedFloor // Momenteel geselecteerde verdieping
```

**Functionaliteit**:
- Toon alle verdiepingen van gebouw
- Selecteer actieve verdieping
- Toon verdiepingsnummer en naam

---

### FloorConfig.jsx
**Locatie**: `src/components/FloorConfig.jsx`

**Doel**: Configuratie van verdieping (plattegrond, access points)

**Props**:
```javascript
floor        // Verdiepingsobject
building     // Gebouw object (context)
onAddFloor   // Callback: (data) => void
onDeleteFloor // Callback: (floorId) => void
```

**Functionaliteit**:
- Toon en wijzig verdiepingsinformatie
- Upload plattegrond afbeelding
- Toon huiding plattegrond
- Voeg/verwijder verdiepingen toe

**Subcomponenten**:
- Afbeelding uploader
- Afbeelding preview

---

### AccessPointList.jsx
**Locatie**: `src/components/AccessPointList.jsx`

**Doel**: Toont alle access points op geselecteerde verdieping

**Props**:
```javascript
accessPoints  // Array van AP objecten
onDelete      // Callback: (apId) => void
onEdit        // Callback: (apId, newData) => void
selectedAP    // Huiding geselecteerde AP
```

**Functionaliteit**:
- Lijst access points in tabel
- Toon BSSID, RSSI, positie
- Verwijder optie per AP
- Toon RSSI visueel (kleurkoding)

---

### AccessPointDrawer.jsx
**Locatie**: `src/components/AccessPointDrawer.jsx`

**Doel**: Interactieve kaart voor placement van access points

**Props**:
```javascript
floorImage   // URL van plattegrondafbeelding
onAddPoint   // Callback: (position, data) => void
existingPoints // Array van bestaande points
```

**Functionaliteit**:
- Toon zoombare/panbare plattegrond
- Klik voor nieuw access point
- Invoerveld voor BSSID en RSSI
- Visueel feedback bij plaatsing
- Verwijder points met klik

**Interactie**:
- Mouse wheel: zoom
- Klik en sleep: pan
- Dubbel klik: point plaatsen

---

## Hooks

### useBuildings()
**Locatie**: `src/hooks/useBuildings.js`

**Doel**: Centraal gebouwen data management

**Returns**:
```javascript
{
  buildings,        // Array
  addBuilding,      // Function
  deleteBuilding,   // Function
  addFloor,         // Function
  deleteFloor,      // Function
  isLoaded         // Boolean
}
```

**Functionaliteit**:
- Load gebouwen van IndexedDB
- CRUD operaties op gebouwen
- CRUD operaties op verdiepingen
- Persisteer naar IndexedDB
- Sync met upload-server

**Voorbeeld Gebruik**:
```jsx
const { buildings, addBuilding } = useBuildings();

const handleAddBuilding = (data) => {
  addBuilding({
    name: data.name,
    address: data.address
  });
};
```

---

## Data Flow

```
App.jsx
  ↓
useBuildings() hook
  ↓
IndexedDB (client-side cache)
  ↓
file-upload-server.js
  ↓
FileSystem
```

---

## Styling

Alle componenten gebruiken **Tailwind CSS**:

```javascript
// Voorbeeld: Knopkleur
className="bg-blue-600 hover:bg-blue-700 text-white"
```

**Globale Thema**:
- Donkerblauw achtergrond: `#0f172a`
- Accent kleur: `#3b82f6` (blauw)
- Tekst: Slate grijs tinten

---

## Best Practices

✅ **Wel doen**:
- Props validatie met PropTypes
- Callback functies als props
- Logische component splitsing
- IndexedDB voor persistentie

❌ **Niet doen**:
- Globale state (wanneer hooks beter zijn)
- Directe DOM manipulatie
- Zware computaties in render

---

## Uitbreiding

Om een nieuw component toe te voegen:

1. Maak bestand in `src/components/ComponentName.jsx`
2. Definieer props en doel
3. Importeer in parent component
4. Voeg PropTypes toe (begin van bestand)
5. Style met Tailwind classes

Voorbeeld template:

```jsx
import PropTypes from 'prop-types';

export default function MyComponent({ prop1, prop2, onAction }) {
  return (
    <div className="p-4 bg-white rounded-lg">
      {/* content */}
    </div>
  );
}

MyComponent.propTypes = {
  prop1: PropTypes.string.isRequired,
  prop2: PropTypes.number,
  onAction: PropTypes.func.isRequired
};
```

---

**Voor meer info zie**: [README.md](./README.md)

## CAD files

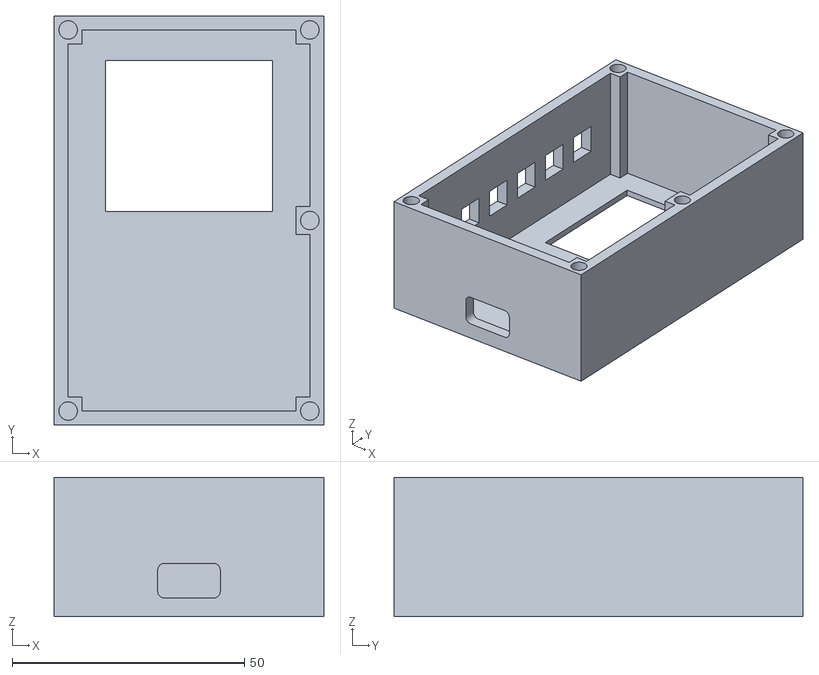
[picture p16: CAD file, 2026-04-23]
hardware/behuizing/Versie 1/voorkant poging 3 12-03.stl
58.0 x 88.0 x 30.0

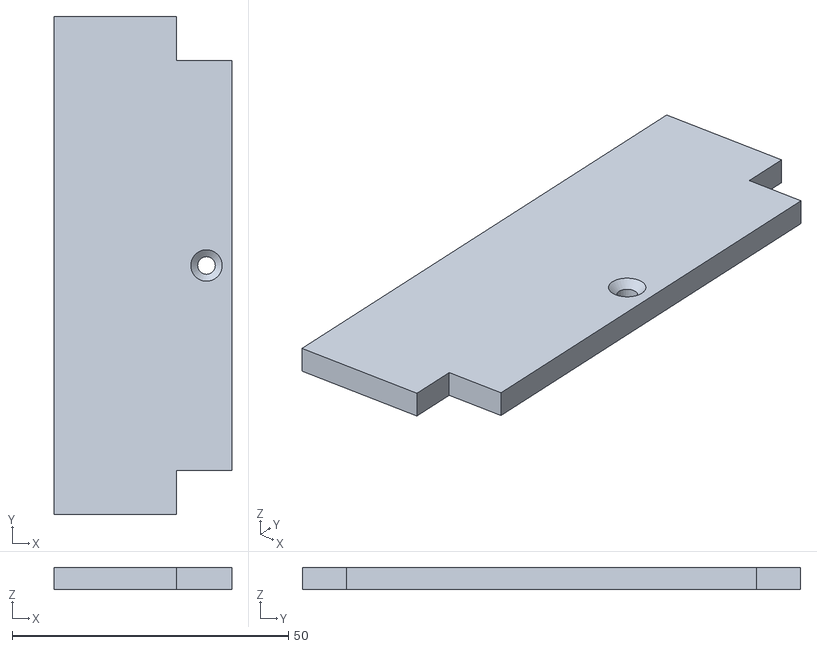
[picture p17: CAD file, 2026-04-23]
hardware/behuizing/Versie 2/panel 26_03.stl
32.2 x 90.2 x 4.00

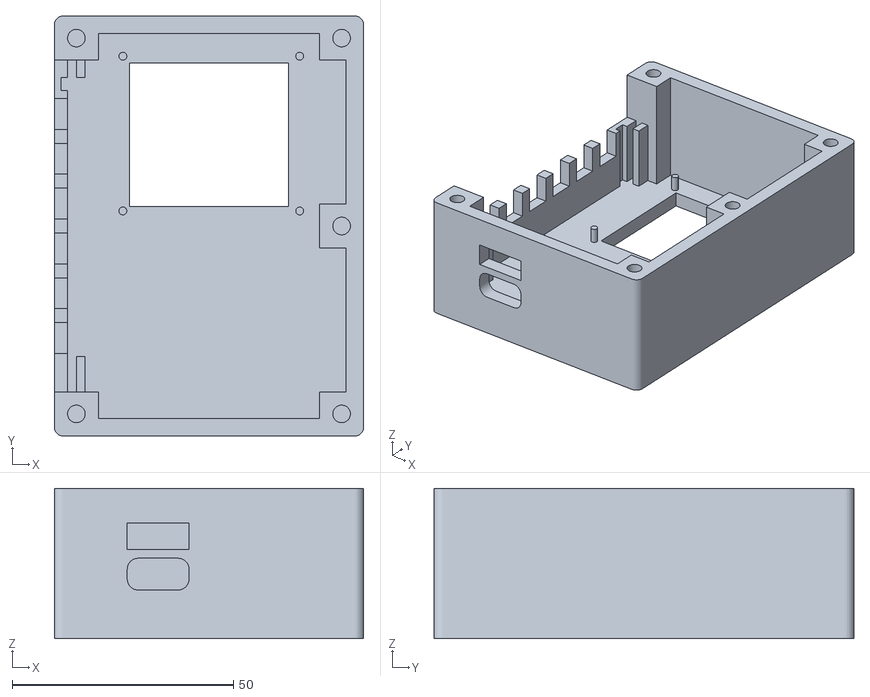
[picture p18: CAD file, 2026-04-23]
hardware/behuizing/Versie 3/voorkant 02-04.stl
70.0 x 95.0 x 34.0

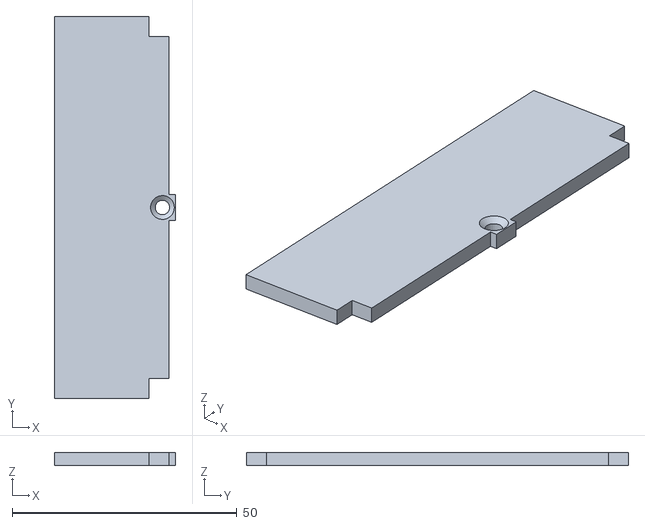
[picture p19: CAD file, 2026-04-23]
hardware/behuizing/Versie 1/alleen batterij acces achterkant poging 2 12-03.stl
26.9 x 85.0 x 3.00

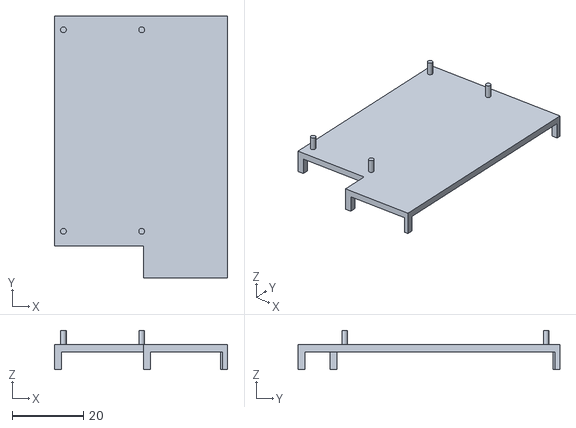
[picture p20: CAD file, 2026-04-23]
hardware/behuizing/Versie 2/tafel 26_03.stl
48.6 x 73.6 x 11.0

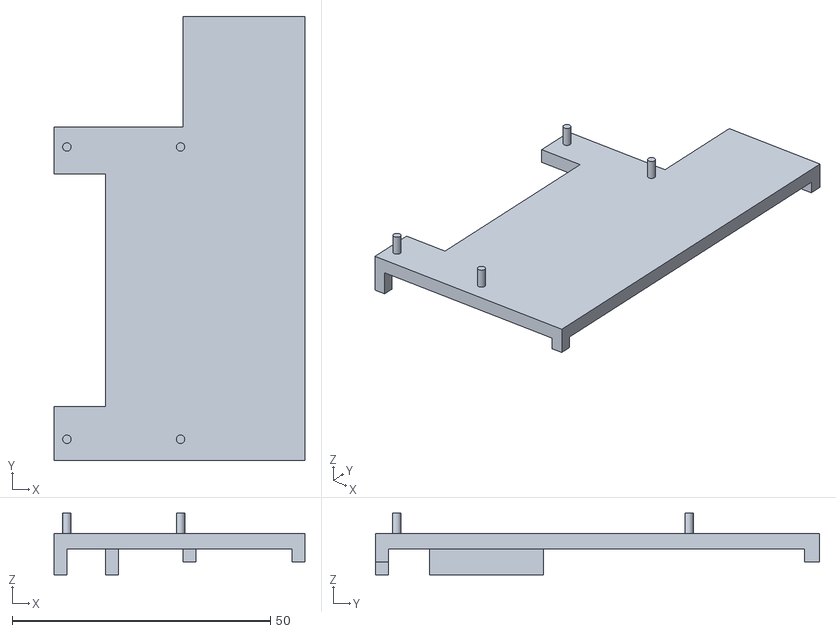
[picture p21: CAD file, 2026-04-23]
hardware/behuizing/Versie 3/tafel 02-04.stl
48.6 x 86.0 x 12.0

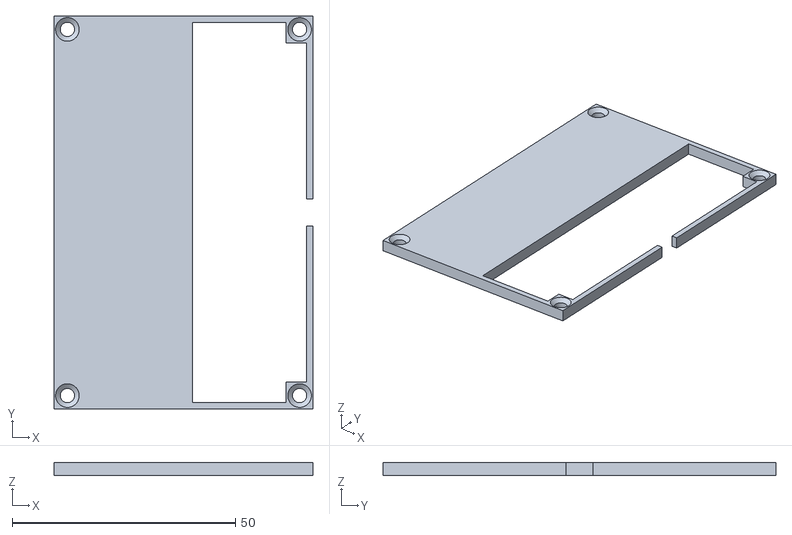
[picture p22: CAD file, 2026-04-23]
hardware/behuizing/Versie 1/alleen deksel achterkant poging 2 12-03.stl
58.0 x 88.0 x 3.00

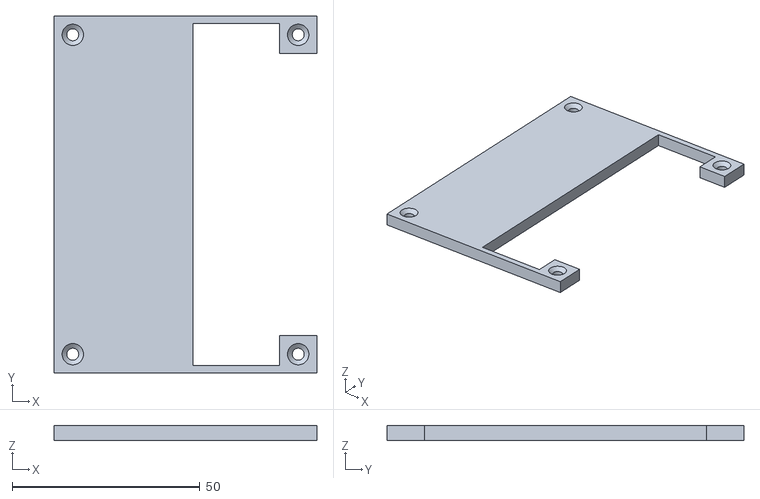
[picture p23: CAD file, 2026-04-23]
hardware/behuizing/Versie 2/achterkant 26_03.stl
70.0 x 95.0 x 4.00

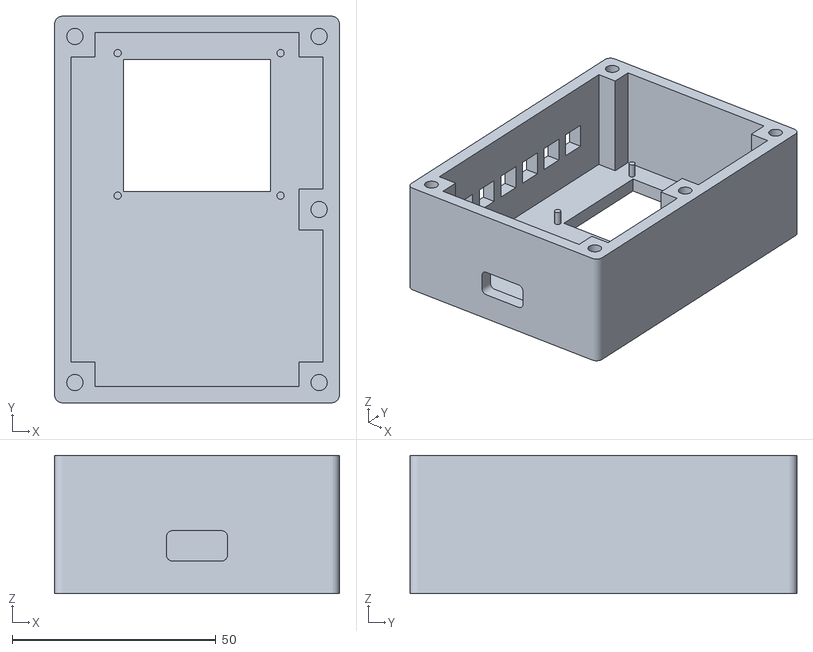
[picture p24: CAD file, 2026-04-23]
hardware/behuizing/Versie 2/voorkant 26_03.stl
70.0 x 95.0 x 34.0

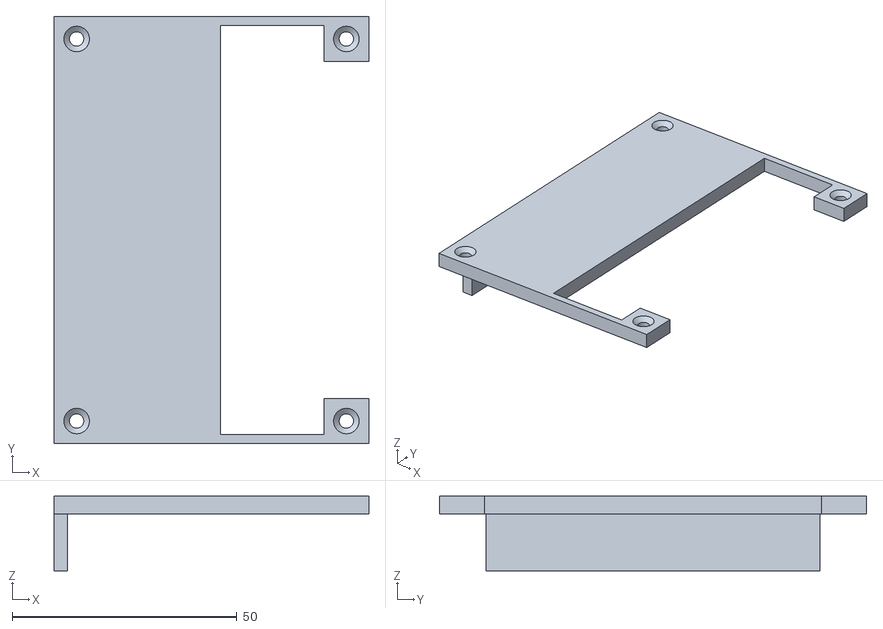
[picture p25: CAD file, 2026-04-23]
hardware/behuizing/Versie 3/achterkant 02-04.stl
70.0 x 95.0 x 16.6

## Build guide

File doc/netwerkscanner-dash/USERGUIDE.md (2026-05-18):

# Netwerkscanner Dash - Gebruikshandleiding

Deze gebruikshandleiding hoort bij de Netwerkscanner Dash front-end. De inhoud hieronder is afgestemd op dit project: korte uitleg, installatie via Docker Compose, bestand-upload en veelvoorkomende problemen.

---

## Inhoud

- [Netwerkscanner Dash - Gebruikshandleiding](#netwerkscanner-dash---gebruikshandleiding)
  - [Inhoud](#inhoud)
  - [Snelstart (Docker Compose)](#snelstart-docker-compose)
  - [Gebruiken van de Dash](#gebruiken-van-de-dash)
  - [Uploaden van scanbestanden](#uploaden-van-scanbestanden)
  - [Configuratie en ontwikkelmodus](#configuratie-en-ontwikkelmodus)
  - [Problemen oplossen](#problemen-oplossen)
  - [Nuttige locaties in de repository](#nuttige-locaties-in-de-repository)

---

## Snelstart (Docker Compose)

1. Vanaf de repository-root start je de services met:

   ```bash
   docker compose up --build -d
   ```

2. Controleer de logs als iets niet start:

   ```bash
   docker compose logs -f
   ```

3. Open de Dash op `http://localhost:8080` (of de poort zoals gedefinieerd in `docker-compose.yml`).

4. Stop de services met:

   ```bash
   docker compose down
   ```

---

## Gebruiken van de Dash

- De Dash toont gescande netwerkgegevens en biedt een eenvoudige upload-interface voor scanbestanden.
- Navigatie: Dashboard, Upload, (optioneel) Settings.
- Dashboard: overzicht van recente scans en statistieken.
- Upload: gebruik het formulier om scanbestanden (meestal JSON) te versturen naar de backend.

---

## Uploaden van scanbestanden

1. Ga naar de Upload-pagina in de Dash.
2. Klik op "Bestand kiezen" of sleep het bestand naar het uploadvlak.
3. Selecteer het juiste scanbestand (JSON) en klik op "Upload".
4. Na succesvolle upload wordt meestal een bevestiging getoond en/of wordt de lijst met scans ververst.

Opmerkingen:

- Controleer bij fouten de backend-logs (`docker compose logs`) voor details.
- Zorg dat het bestandstype overeenkomt met wat de backend verwacht (JSON).

---

## Configuratie en ontwikkelmodus

- Optioneel lokaal (zonder Docker):

```bash
cd Netwerkscanner/netwerkscanner-dash
npm install
npm run dev
```

- Voor productie: gebruik `npm run build` en host de inhoud van `dist/`.
- API-endpoints en proxy-instellingen kunnen in `vite.config.js` of via environment-variabelen worden aangepast.

---

## Problemen oplossen

- Dashboard niet bereikbaar: controleer `docker compose ps` en `docker compose logs`.
- Upload werkt niet: bekijk backend-logs en controleer bestandsgrootte/format.
- Foutmeldingen in frontend: open de browser console (F12) voor netwerk- en JS-errors.

---

## Nuttige locaties in de repository

- Frontend bron: [Netwerkscanner/netwerkscanner-dash/src/](../../software/netwerkscanner-dash/src/)
- Upload-backend: [Netwerkscanner/netwerkscanner-dash/file-upload-server.js](../../software/netwerkscanner-dash/file-upload-server.js)
- Docker-compose: [docker-compose.yml](../../docker-compose.yml) en [netwerkscanner-dash/Dockerfile](../../software/netwerkscanner-dash/Dockerfile)
- Documentatie (dit dossier): [doc/netwerkscanner-dash/](./)

---

**Laatst bijgewerkt**: 2026
**Versie**: 1.1.0

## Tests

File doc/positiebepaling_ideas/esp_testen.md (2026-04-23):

# test1 esp32

resultaat
```
7 networks found
Nr | SSID                             | RSSI |  | BSSID                    | CH | Encryption
 1 | Home sweet Home                  |  -80 |  | BSSID: AA:02:B8:6C:AA:D2 | 11 | WPA2
 2 | Orange-c7697                     |  -92 |  | BSSID: AA:6A:0A:2C:AA:9B |  1 | WPA2
 3 | JEAN                             |  -93 |  | BSSID: AA:24:72:4A:AA:C9 |  6 | WPA2
 4 | Proximus-Home-612796             |  -94 |  | BSSID: AA:05:95:FB:AA:61 |  6 | WPA2
 5 | Proximus-Home-832025             |  -95 |  | BSSID: AA:E3:1A:CD:AA:04 |  6 | WPA2
 6 | Proximus-Home-775089             |  -96 |  | BSSID: AA:B8:2B:8D:AA:E4 | 11 | WPA2+WPA3
 7 | Proximus-Home-D280               |  -97 |  | BSSID: AA:5D:9E:CB:AA:86 |  1 | WPA2

```

RSSI waarde veranderingen op stationaire locatie  
min = -75  
max = -80  

Het aantal gevonden netwerken verschild veel gaat van min 2 tot soms 8 

We kunnen deze problemen mogelijk verkleinen met een betere antenne.

# test2 

Door deze lijn code toe te voegen gaan de metingen beter.  ```WiFi.setSleep(false);  ```  

Maakt RSSI veel nauwkeuriger  
min = -78  
max = -79  

Gevonden netwerken nu tussen 6 en 8, een grote verbetering.  

# test 3

1. WiFi.scanNetworks(false, true, false, 80);

resultaat  
```
gemiddelde voor 1 scan = 5395
gemiddelde voor 1 scan = 5395
gemiddelde voor 1 scan = 5395
```

2. ```WiFi.scanNetworks(false, true, true, 80);``` prob aan.  

resultaat  
```
gemiddelde voor 1 scan = 1128
gemiddelde voor 1 scan = 1128
gemiddelde voor 1 scan = 1128
gemiddelde voor 1 scan = 1128
```

478% sneller. Dit klop beter met de berekende tijd 14ch * 80ms = 1120.  
Scantijden blijven ook heel consistent.

op school ook dezelfde tijden  
```
gemiddelde voor 1 scan = 1129
gemiddelde voor 1 scan = 1129
gemiddelde voor 1 scan = 1129
```

test op school
´´´
Scan start
Scan done
28 networks found
Nr | SSID                             | RSSI |  | BSSID                    | CH | Encryption
 1 | DIRECT-HC0S1EBB00701GOAD         |  -44 |  | BSSID: 11:BB:9E:95:AB:22 | 11 | WPA2
 2 | MPSK                             |  -59 |  | BSSID: 11:BA:25:4F:EB:22 | 11 | WPA2
 3 | eduroam                          |  -59 |  | BSSID: 11:BA:25:4F:EB:22 | 11 | WPA2-EAP
 4 | campusroam                       |  -59 |  | BSSID: 11:BA:25:4F:EB:22 | 11 | WPA2-EAP
 5 | VIVES-GUEST                      |  -59 |  | BSSID: 11:BA:25:4F:EB:22 | 11 | open
 6 |                                  |  -59 |  | BSSID: 11:BA:25:4F:EB:22 | 11 | WPA2
 7 | VIVES-EVENT                      |  -59 |  | BSSID: 11:BA:25:4F:EB:22 | 11 | open
 8 |                                  |  -59 |  | BSSID: 11:BA:25:4F:EB:22 | 11 | WPA2
 9 | devbit                           |  -60 |  | BSSID: 11:8B:A9:15:5F:22 |  1 | WPA2
10 | iotlab                           |  -60 |  | BSSID: 11:8B:A9:15:5F:22 |  1 | WPA2
11 | devbit                           |  -70 |  | BSSID: 11:8B:A9:15:60:22 |  6 | WPA2
12 | iotlab                           |  -70 |  | BSSID: 11:8B:A9:15:60:22 |  6 | WPA2
13 | campusroam                       |  -73 |  | BSSID: 11:BA:25:50:1B:22 |  1 | WPA2-EAP
14 |                                  |  -73 |  | BSSID: 11:BA:25:50:1B:22 |  1 | WPA2
15 |                                  |  -73 |  | BSSID: 11:BA:25:50:1B:22 |  1 | WPA2
16 | eduroam                          |  -74 |  | BSSID: 11:BA:25:50:1B:22 |  1 | WPA2-EAP
17 | MPSK                             |  -74 |  | BSSID: 11:BA:25:50:1B:22 |  1 | WPA2
18 | VIVES-EVENT                      |  -74 |  | BSSID: 11:BA:25:50:1B:22 |  1 | open
19 | Coco 🥥                         |  -77 |  | BSSID: 11:DD:00:4E:02:22|  6 | WPA2+WPA3
20 | campusroam                       |  -83 |  | BSSID: 11:BA:25:50:27:22 | 11 | WPA2-EAP
21 |                                  |  -84 |  | BSSID: 11:BA:25:50:27:22 | 11 | WPA2
22 | VIVES-EVENT                      |  -84 |  | BSSID: 11:BA:25:50:27:22 | 11 | open
23 |                                  |  -84 |  | BSSID: 11:BA:25:50:27:22 | 11 | WPA2
24 | MPSK                             |  -84 |  | BSSID: 11:BA:25:50:27:22 | 11 | WPA2
25 | eduroam                          |  -84 |  | BSSID: 11:BA:25:50:27:22 | 11 | WPA2-EAP
26 | VIVES-GUEST                      |  -87 |  | BSSID: 11:BA:25:50:26:22 |  1 | open
27 | MPSK                             |  -88 |  | BSSID: 11:BA:25:50:26:22 |  1 | WPA2
28 | VIVES-EVENT                      |  -89 |  | BSSID: 11:BA:25:50:26:22 |  1 | open
´´´

Als we goed kijken zien we dat sommige netwerken een bijna identiek bssid hebben.
Enkel de laatste waarde veranderd. 1 acces point heeft meerdere netwerken die hij uitstuurt.  

Dit is belangrijk om te weten omdat als we triangulatie willen doen dat we niet met 3 dezelfde de positie proberen te bepalen.

# test 4

opstelling gemaakt met 3 esp8266 acces points.
test van de Trilateratie geeft negatieve en foute waarden.  
Door het ingeven van eigen waarden zie ik dat de formule werkt maar geeft negative waarden terug.
De fouten waarden komen door de nog niet nauwkeurige afstand bepaling naar de ap's

# test 5 
esp hebben nu allemaal goede antennes, rssi waarden zijn nu gelijkaardig als ze op dezelfde plaats staan.  

# test 6 
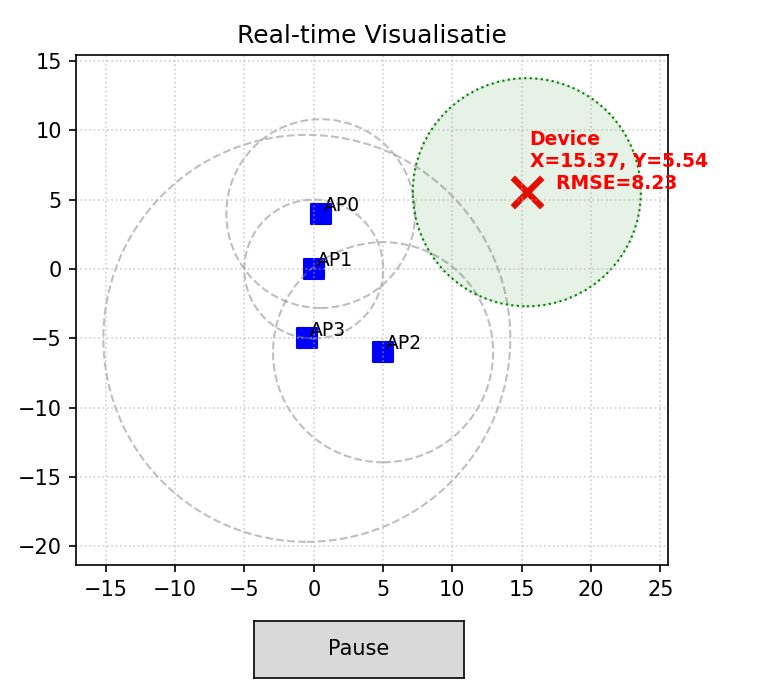
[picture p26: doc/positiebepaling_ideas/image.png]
positie bepaling werkt ongeveer, ap3 heeft een object in de weg waardoor hij denk verder te zijn waardoor de geschatte positie word weg geduwd in die richting.  

# test 7
ap verplaatst en obstakels zo veel mogelijk verminderd. mijn locatie is X=2 Y=2
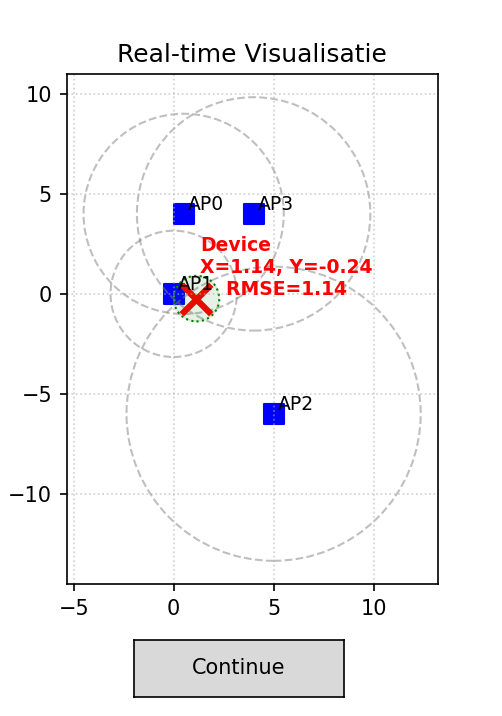
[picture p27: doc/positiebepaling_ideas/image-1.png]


# test 8 
Met 4 ap gaat het al beter maar er moet nog aangepast worden dat korte afstanden meer doorwegen dan de lange. Naar mijn aanvoelen kan je de positie schatten in een straal van 5m van de echte locatie. personen in de ruimte verstoren ook de metingen. verschil meten met de ftm zal dat mogelijk verbeteren.
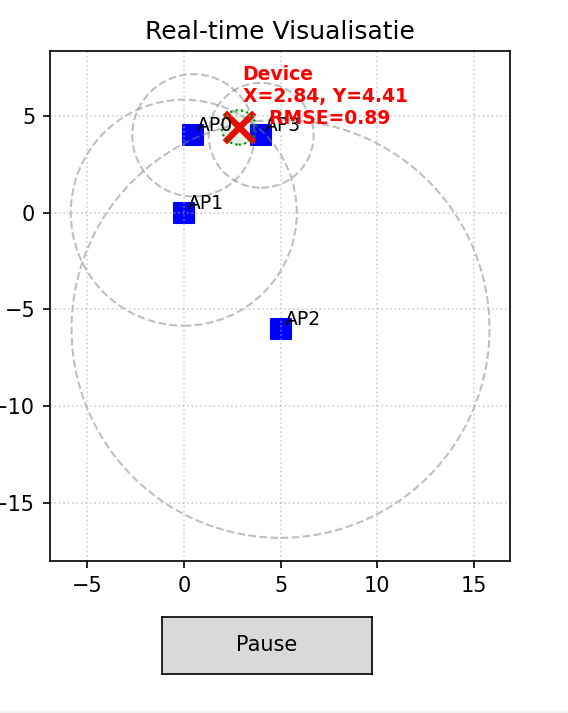
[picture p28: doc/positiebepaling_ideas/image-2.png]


# idee
de pcb antennen ontvangt niet uniform in alle richtingen.  
wat als we nu de esp nu rap laten ronddraaien zodat het een gemiddelde word.

# test 9
De nieuwe positie berekening manier werkt stukken beter dan de vorige maar nog niet perfect. moest de antenne minder directioneel zijn vermoed ik dat het beter zou zijn.
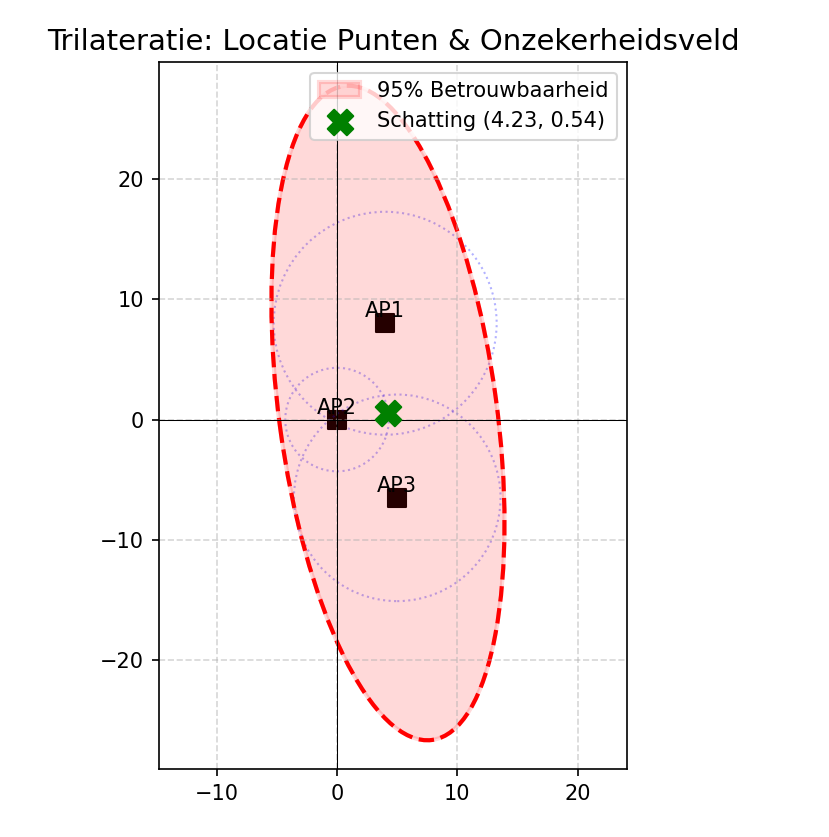
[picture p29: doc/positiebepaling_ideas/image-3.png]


# test 10
Op school zelfde resultaat als thuis niet zo nauwkeurig
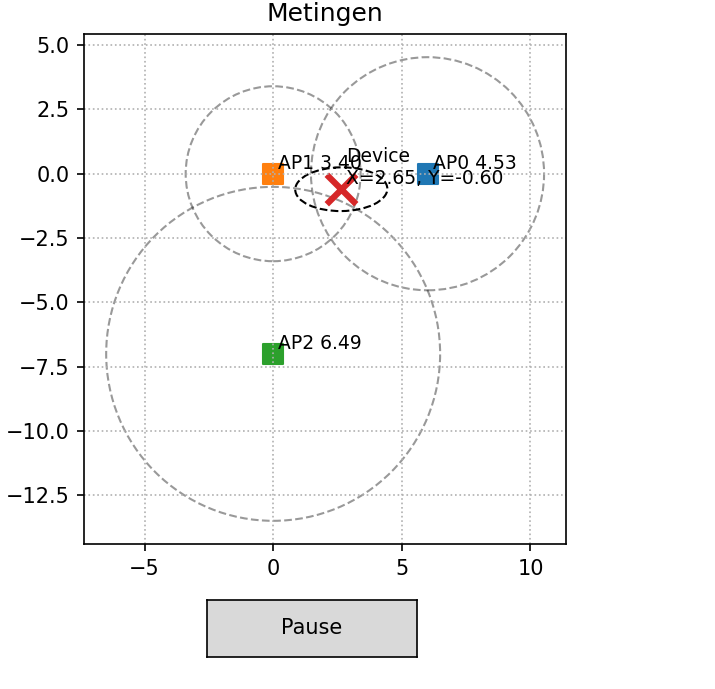
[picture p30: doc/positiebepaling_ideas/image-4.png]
 

# test 11
simple fingerprinting.  
werkt soms maar is voorlopig nog onnauwkeuriger dan de trilateratie.
De fout was zit in het berkeden.
Ik neem de som van het verschil tussen de huidige meting en de het datapunt.
Maar as een datapunt niet veel netwerken overeenkomend heeft zal deze altijd de kleinste fout hebben en zal het denken daar te zijn.

heb dit verbeterd door te delen door het aantal netwerken die de huidige locatie gevonden heeft.

heb het nog verbeterd door een counter te zetten in de datapoint class die bijhoud hoeveel netwerken er nu echt meetellen

# test 12
gemiddelde van enkel de overeenkomstige netwerken is veelbelovend.
tijdens de test in 3 ruimtes is het 3 van de 10 keer fout.
door hetzelfde ruimte meerdere keren te scannen en toe te voegen aan de datapunten is het accurater in het voorspelen van de locatie

Het zou een idee kunnen zijn om op elke fingerprint locatie een min en max en gemiddelde bij te houden per netwerk. en bij het bereken van de locatie dan procentueel de rssi fout verschillend te laten meetellen.

# test 13
Op school hetzelfde resultaat als thuis.

# test 14 
Succes!!! Door een logica fout in de code werd telkens een mac address niet gevonden werd stopte de loop met vergelijken voor alle volgende mac adressen. De oplossing was om enkel die ene over te slaan.  
Momenteel kan het systeem de postie bepalen met een afstand van ongeveer 4 meter tussen de datapunten.

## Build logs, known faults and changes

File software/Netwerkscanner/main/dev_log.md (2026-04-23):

# waarom gebruikt het scherm geen library?
als ik een library wil toevoegen is het altijd miserie dat het het h bestand niet vind of het vind het enkel in de main of in een cpp bestand(onvoorspelbaar). Ook loop de programmeer omgeving vast en vind het plots de wifi library niet ook al heeft het er normaal geen invloed op.

# verbruik van task's 27/03/2026
--- [CPU GEBRUIK] (uS = Tijd actief | % = Belasting) ---
monitorCpuTask  1128668         1%
IDLE            94487608                97%
tiT             47990           <1%
nimble_host     3350            <1%
MenuTask        51292           <1%
Tmr Svc         6               <1%
TryConnectToWif 3996            <1%
esp_timer       64987           <1%
wifi            1422851         1%
sys_evt         1275            <1%
ble_ll_task     1454            <1%

--- [TAAK STATUS] (X=Run, R=Ready, B=Blocked, S=Suspended) ---
Naam            Stat    Prio    VrijeStack      ID
monitorCpuTask  X       6       1376    18
IDLE            R       0       1256    3
tiT             B       18      2616    5
MenuTask        B       5       2188    10
Tmr Svc         B       1       1784    4
TryConnectToWif B       7       1980    11
sys_evt         B       20      916     6
wifi            B       23      3756    7
esp_timer       S       22      3600    1
ble_ll_task     B       23      3596    8
nimble_host     B       21      2148    9

# macro collision
oplossing  
//Moet hier staan anders compile error door combinatie van  
//lwIP en Arduino  
#ifdef INADDR_NONE  
#undef INADDR_NONE  
#endif  

#ifdef INADDR_ANY  
#undef INADDR_ANY  
#endif  

# button up triggert 2 keer
de andere knoppen doen normaal

trig bij induwen  
rig bij loslaten  

condensators lossen het niet op.  
```cpp
static void IRAM_ATTR buttonIsrUp(void *arg)
{
    uint64_t now = esp_timer_get_time();
    int currentState = gpio_get_level(GPIO_BUTTON_UP);

    if (now - lastIsrTimeUp > DEBOUNCE_DELAY)
    {
        // RISING EDGE: Hardware is HOOG, maar software dacht nog LAAG
        if (currentState == 1 && pressedUp == 0)
        {
            ButtonEventT event = BUTTON_UP;
            xQueueSendFromISR(menuQueue, &event, NULL);
            
            pressedUp = 1;        // Zet vlag op "ingedrukt"
            lastIsrTimeUp = now;
        }
        // FALLING EDGE: Hardware is LAAG, maar software dacht nog HOOG
        else if (currentState == 0 && pressedUp == 1)
        {
            // We sturen geen event naar de queue (zoals gevraagd),
            // maar we resetten de vlag zodat de volgende klik weer werkt.
            pressedUp = 0;        
            lastIsrTimeUp = now;  // (negeert release-dender)
        }
    }
}
```
Anyedge Interrupt: De ISR wordt bij elke verandering (stijgend en dalend) aangeroepen.

Zelf-correctie: Als gpio_get_level() door dender een verkeerde waarde leest (bijv. 0 terwijl je drukt), faalt de if-check. Omdat de tijdstempel (lastIsrTimeUp) dan niet wordt bijgewerkt, blijft de deur openstaan voor de volgende dender-puls (microseconden later) die wél de juiste waarde leest.

Lock-out: Zodra een stabiele waarde (1 bij press, 0 bij release) is geregistreerd, blokkeert de DEBOUNCE_DELAY alle volgende interrupts voor 50ms.

# down button triggert nu meer
dit komt door de condensators die zorgen dat het uitgaan langzamer gaat en bij down is dit een grotere dan de andere.

# static volatile uint64_t lastIsrTimeUp = 0;
static is zodat het enkel in het bestand kan gebruikt worden.
Onthouden (Variabelen): Als je static binnen een functie gebruikt, wordt de waarde niet vergeten als de functie klaar is. Bij de volgende klik staat de oude tijd er nog in.

# condensators weg gedaan 
interrupt werkt niet meer

# het werkt met dit 
```cpp
static void IRAM_ATTR buttonIsrUp(void *arg)
{
    uint64_t now = esp_timer_get_time();

    // 1. Harde debounce: negeer alles binnen 50ms (50000 us)
    if (now - lastIsrTimeUp < 50000) {
        return;
    }

    // 2. Omdat we geen digitalRead doen, vertrouwen we op de 'state'
    if (!pressedUp) {
        // We gaan ervan uit dat dit de RISING edge is
        ButtonEventT event = BUTTON_UP;
        xQueueSendFromISR(menuQueue, &event, NULL);
        
        pressedUp = true;
        lastIsrTimeUp = now;
    } else {
        // We gaan ervan uit dat dit de FALLING edge is
        pressedUp = false;
        lastIsrTimeUp = now;
    }
}
```

# stappen plan

# CPU verbruik bij scannen
--- [CPU GEBRUIK] (uS = Tijd actief | % = Belasting) ---
MonitorCpuTask  819484          <1%
IDLE            192341844               97%
tiT             104539          <1%
ScannerTask     56346           <1%
nimble_host     3249            <1%
sys_evt         3636            <1%
MenuTask        104479          <1%
Tmr Svc         7               <1%
esp_timer       120911          <1%
wifi            3057733         1%
TryConnectToWif 7165            <1%
ble_ll_task     1461            <1%

Ik zie dat de cpu niet veel tijd moet steken tijdens het scannen.  
Ik kan dus andere taken uitvoeren tijdens het scannen.

# ota (over the air update)
partitie waren niet groot genoeg om nieuw programma op te zetten.

# memory leak
na 1 min scannen crasht het programma.
mogelijk door json die payload niet free();
het was inderdaad dat.

# 
er werd geen melding naar de queue gestuurd al het verbonden is met de server.

# memory error
als er teveel netwerken gevonden worden kan de json niet gemaakt worden omdat het te groot wordt.
Door dat de taken apart zitten was het telkens net voor de 2de keer scannen waardoor ik eerst in de foute taak de fout zat te zoeken.

# test max send ap's
23 gaat maar had 1 keer als het nog aan het verbinden met wifi was dat het crashte.
30 lukt ook

# toekomst
Presence Detection: Detecteer wanneer een specifiek MAC-adres (bijvoorbeeld je eigen telefoon) in de buurt is en schakel een lamp in.

Channel Occupancy Monitor: Analyseer welke kanalen het drukst zijn (meeste beacons) om je eigen router optimaal in te stellen.

Rogue AP Detection: Scan op Access Points met jouw SSID die niet jouw MAC-adres hebben (om "Evil Twin" aanvallen op jezelf te detecteren).

# rtos
Ik heb een cruciale denkfout gemaakt. Als je in rtos wil dat de taken wisselen elke 1ms dan moeten ze dezelfde prioriteit hebben. anders heeft de hoogste altijd voorrang.

# json
wifi json zend nu alle netwerken als er meer dan 30 zijn.

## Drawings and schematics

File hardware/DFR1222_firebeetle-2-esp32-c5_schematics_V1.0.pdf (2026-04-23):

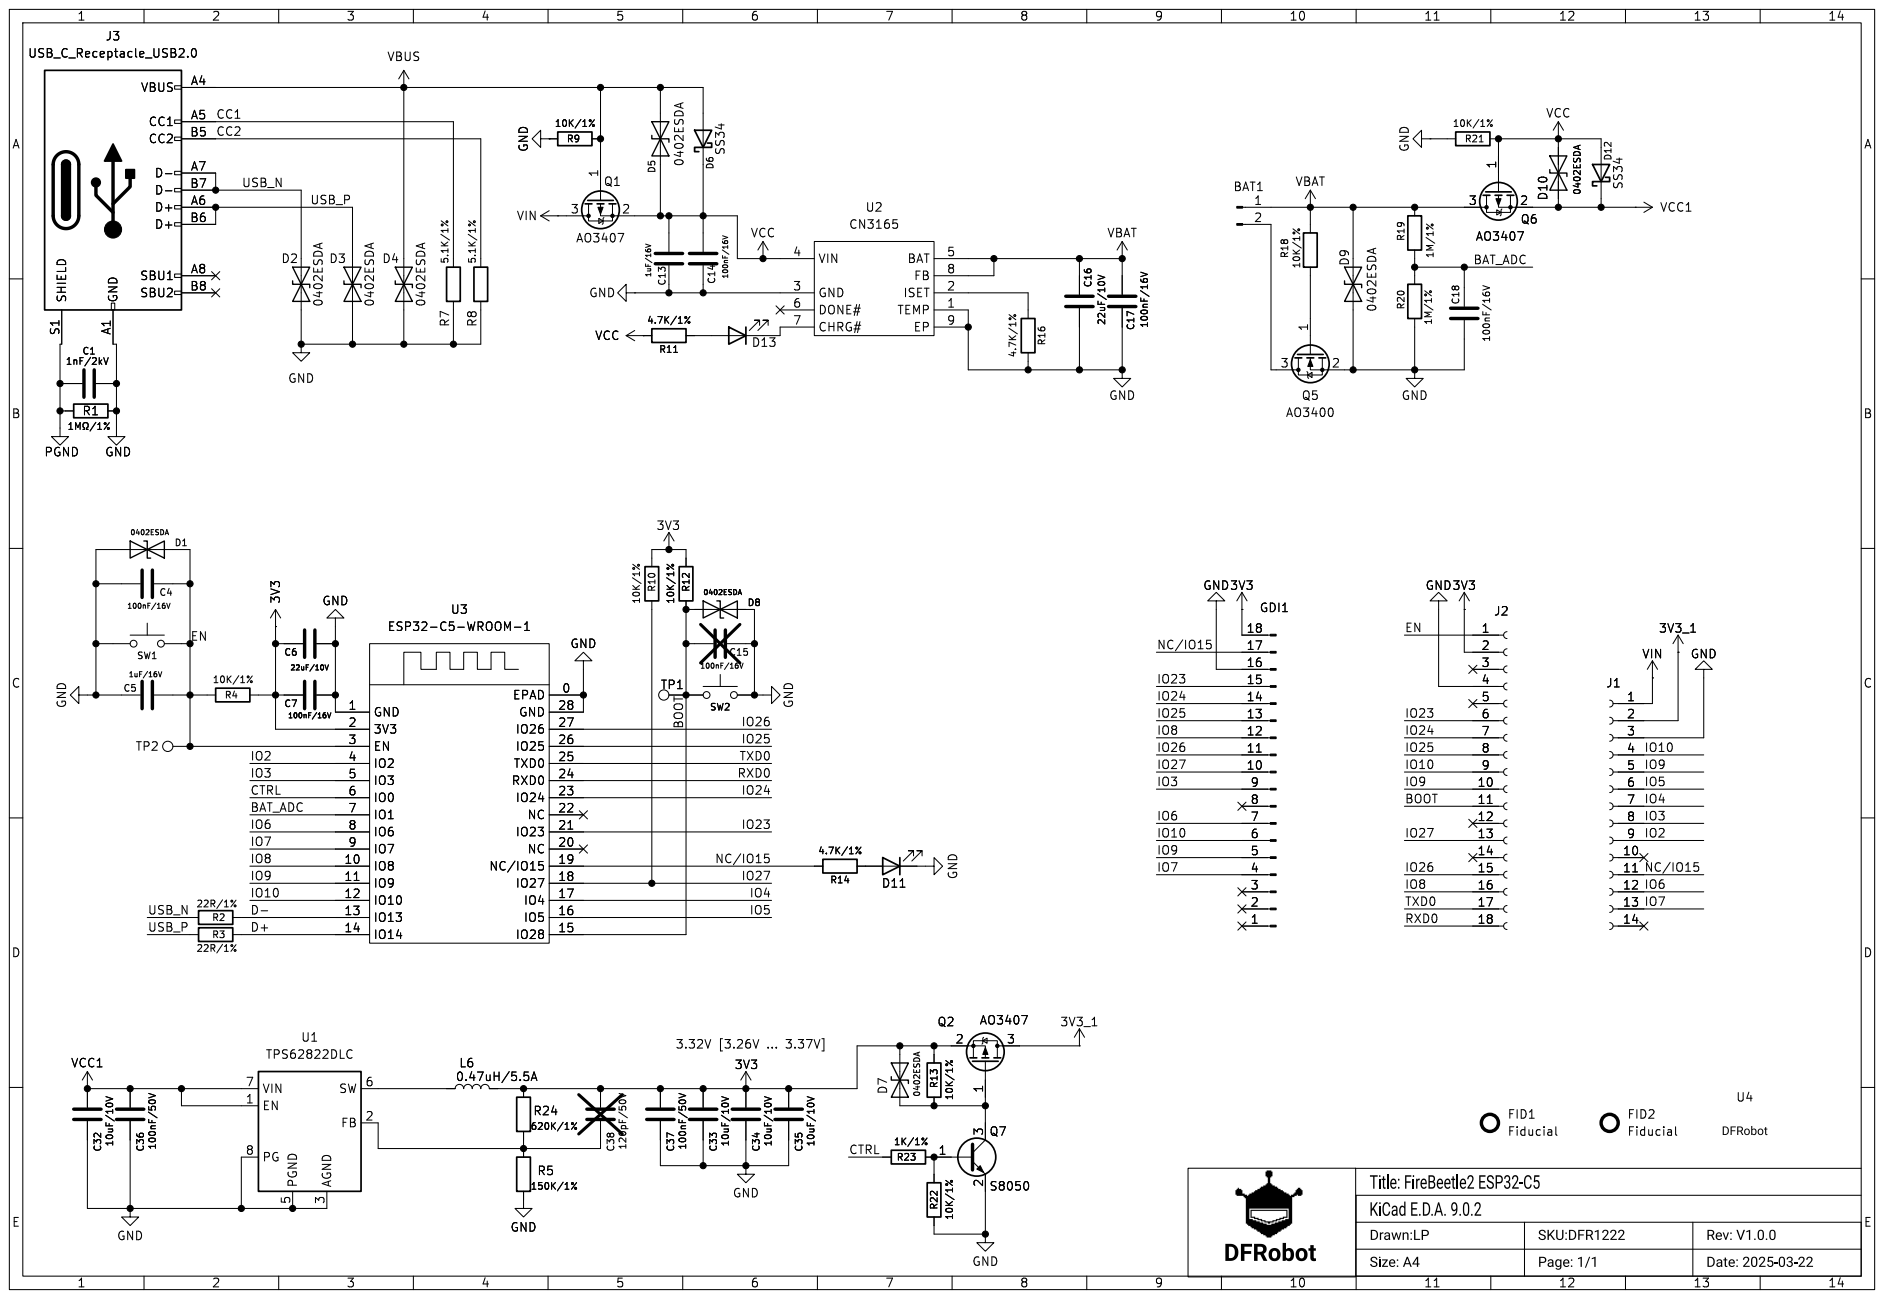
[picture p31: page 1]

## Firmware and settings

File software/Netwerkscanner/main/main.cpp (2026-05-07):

#include "driver/gpio.h"
#include "esp_clk_tree.h"
#include "esp_event.h"
#include "esp_log.h"
#include "esp_netif.h"
#include "esp_ota_ops.h"
#include "esp_system.h"
#include "esp_wifi.h"
#include "freertos/FreeRTOS.h"
#include "freertos/semphr.h"
#include "freertos/task.h"
#include "host/ble_hs.h"
#include "lwip/sockets.h"
#include "nimble/nimble_port.h"
#include "nimble/nimble_port_freertos.h"
#include "nvs_flash.h"
#include "services/gap/ble_svc_gap.h"

// Moet hier staan anders compile error door combinatie van
// lwIP en Arduino
#ifdef INADDR_NONE
#undef INADDR_NONE
#endif

#ifdef INADDR_ANY
#undef INADDR_ANY
#endif

// #include <Arduino.h>
#include "Test.h"
#include "WiFi.h"
#include "api.h"
#include "http_post.h"
#include "main.h"
#include "ota_server.h"
#include "screen.h"
#include "simple_fingerprinting.h"
#include "time_sync.h"
#include "wifi_key.h"

#define ENABLE_CPU_MONITOR 1
#define ARRAY_SIZE(x) (sizeof(x) / sizeof(x[0]))

static const char* LOGTAG = "MAIN.CPP";

#define GPIO_3V3 GPIO_NUM_0

#define DEBOUNCE_DELAY 60
#define GPIO_BUTTON_UP GPIO_NUM_2      // A1
#define GPIO_BUTTON_DOWN GPIO_NUM_4    // A3
#define GPIO_BUTTON_SELECT GPIO_NUM_5  // A4
#define GPIO_BUTTON_BACK GPIO_NUM_9    // SDA
#define GPIO_BUTTON_MULTI GPIO_NUM_10  // SDL
static volatile uint64_t lastIsrTimeUp = 0;
static volatile uint64_t lastIsrTimeDown = 0;
static volatile uint64_t lastIsrTimeSelect = 0;
static volatile uint64_t lastIsrTimeBack = 0;
static volatile uint64_t lastIsrTimeMulti = 0;
static volatile bool pressedUp = 0;
static volatile bool pressedDown = 0;
static volatile bool pressedSelect = 0;
static volatile bool pressedBack = 0;
static volatile bool pressedMulti = 0;

// typedef enum {
//   BUTTON_UP,
//   BUTTON_DOWN,
//   BUTTON_SELECT,
//   BUTTON_BACK,
//   BUTTON_MULTI,
//   EVENT_WIFI_CONNECTED,
//   EVENT_WIFI_DISCONNECTED,
//   EVENT_LOCATION
// } ButtonEventT;

typedef struct {
  wifi_ap_record_t* records;
  uint16_t count;
  uint64_t timeStart;
  uint64_t timeEnd;
} scanWifiResults_t;

typedef struct {
  char mac[18];
  uint16_t rssi;
  uint64_t timeDetection;
  uint16_t scanId;
} scanBluethoothResults_t;

typedef struct {
  bool wifi2_4Ghz;
  bool wifi5Ghz;
  bool bluetooth;
} ScanConfig_t;

ScanConfig_t GlobalScanConfig = {false, false, false};

QueueHandle_t menuQueue = NULL;
static QueueHandle_t wifiQueue;
static QueueHandle_t BluetoothQueue;
static QueueSetHandle_t combinedQueueSet;

TaskHandle_t xScannerHandle = NULL;
TaskHandle_t xMonitorCpuHandle = NULL;

#define WIFI_CONNECTED_BIT BIT0    // verbondenMetWifi
#define SERVER_CONNECTED_BIT BIT1  // verbondenMetServer

static EventGroupHandle_t communicationStateGroup;

typedef struct {
  const char* ssid;
  const char* password;
} WifiCredentials_t;
static const WifiCredentials_t myWifiNetworks[] = {
    {WIFI_SSID_0, WIFI_PASSWORD_0},  // in wifi_key.h
    {WIFI_SSID_1, WIFI_PASSWORD_1},
};
#define MAX_NETWORKS (sizeof(myWifiNetworks) / sizeof(myWifiNetworks[0]))
static int currentMyWifiNetworksIndex = 0;

wifi_country_t countryBe = {
    .cc = "BE",          // Landcode
    .schan = 1,          // Startkanaal (meestal 1)
    .nchan = 13,         // Aantal kanalen voor 2.4GHz (1 t/m 13)
    .max_tx_power = 20,  // Maximaal zendvermogen (in dBm)
    .policy = WIFI_COUNTRY_POLICY_AUTO,  // Gebruik instellingen van verbonden
                                         // AP of lokaal
                                         //.wifi_5g_channel_mask
};

LocationBasket_t LocationBasket;
SemaphoreHandle_t LocationMutex;

void CheckCpuFreq() {
  uint32_t freq_hz;
  // Get the frequency of the CPU clock
  esp_clk_tree_src_get_freq_hz(SOC_MOD_CLK_CPU,
                               ESP_CLK_TREE_SRC_FREQ_PRECISION_EXACT, &freq_hz);
  printf("CPU Clock: %lu Hz\n", freq_hz);
}
const char* Str(const char* prefix, int8_t val) {
  static char buf[32];  // static zorgt dat de tekst blijft bestaan na de return
  snprintf(buf, sizeof(buf), "%s%d", prefix, val);
  return buf;
}
void GetMyIp(char* ipAddress) {
  esp_netif_ip_info_t ipInfo;
  esp_netif_t* netif = esp_netif_get_handle_from_ifkey("WIFI_STA_DEF");

  if (netif != NULL && esp_netif_get_ip_info(netif, &ipInfo) == ESP_OK) {
    esp_ip4addr_ntoa(&ipInfo.ip, ipAddress, 16);
  } else {
    strcpy(ipAddress, "0.0.0.0");
  }
}
void PrintConfiguredChannels(const wifi_scan_config_t* ScanConfig) {
  printf("\n--- Actieve Scan Kanalen ---\n");

  printf("2.4GHz: ");
  bool found24 = false;
  for (int i = 1; i <= 14; i++) {
    if (ScanConfig->channel_bitmap.ghz_2_channels & (1 << i)) {
      printf("[%d] ", BIT_NUMBER_TO_CHANNEL(i, WIFI_BAND_2G));
      found24 = true;
    }
  }
  if (!found24) printf("Geen");

  printf("\n5GHz:   ");
  bool found5 = false;
  for (int i = 0; i <= 32; i++) {
    if (ScanConfig->channel_bitmap.ghz_5_channels & (1ULL << i)) {
      printf("[%d] ", BIT_NUMBER_TO_CHANNEL(i, WIFI_BAND_5G));
      found5 = true;
    }
  }
  if (!found5) printf("Geen");
  printf("\n---------------------------\n");
}
void MonitorCpuTask(void* pvParameters) {
  char buffer[1024];
  while (1) {
    printf("\n--- [CPU GEBRUIK] (uS = Tijd actief | %% = Belasting) ---\n");
    vTaskGetRunTimeStats(buffer);
    printf("%s\n", buffer);

    printf("--- [TAAK STATUS] (X=Run, R=Ready, B=Blocked, S=Suspended) ---\n");
    printf("Naam\t\tStat\tPrio\tVrijeStack\tID\n");
    vTaskList(buffer);
    printf("%s\n", buffer);

    vTaskDelay(pdMS_TO_TICKS(5000));
  }
}

int waitForUserNumber() {
  char buffer[32];
  int i = 0;

  printf("Wachten op invoer (getal + Enter)...\n");

  while (1) {
    int c = fgetc(stdin);

    if (c == EOF) {
      vTaskDelay(pdMS_TO_TICKS(10));
      continue;
    }

    putchar(c);

    if (isdigit(c) || (c == '-' && i == 0)) {
      if (i < sizeof(buffer) - 1) {
        buffer[i++] = (char)c;
      }
    } else if (c == '\n' || c == '\r') {
      if (i > 0) {
        buffer[i] = '\0';
        printf("\n");
        return atoi(buffer);
      } else {
        printf("\nVoer eerst een getal in: ");
      }
    }
  }
}

void PrintFreeStackSize() {
  ESP_LOGI("Free Stack", "Taak: %s | Vrij: %u bytes", pcTaskGetName(NULL),
           (unsigned int)uxTaskGetStackHighWaterMark(NULL));
}

static void BluethoothHostTask(void* param) {
  // NimBLE host stack begint hier te draaien
  nimble_port_run();
  nimble_port_freertos_deinit();
}
static int ble_gap_event_handler(struct ble_gap_event* event, void* arg) {
  switch (event->type) {
    case BLE_GAP_EVENT_DISC:
      printf(
          "BLE Device Found: RSSI %d | Addr: %02x:%02x:%02x:%02x:%02x:%02x "
          "rssi %02x \n",
          event->disc.rssi, event->disc.addr.val[5], event->disc.addr.val[4],
          event->disc.addr.val[3], event->disc.addr.val[2],
          event->disc.addr.val[1], event->disc.addr.val[0], event->disc.rssi);

      scanBluethoothResults_t result;
      snprintf(result.mac, sizeof(result.mac), "%02x:%02x:%02x:%02x:%02x:%02x",
               event->disc.addr.val[5], event->disc.addr.val[4],
               event->disc.addr.val[3], event->disc.addr.val[2],
               event->disc.addr.val[1], event->disc.addr.val[0]);
      result.rssi = event->disc.rssi;
      result.scanId = 0;
      result.timeDetection = TimeSync::Get();

      if (xQueueSend(BluetoothQueue, &result, pdMS_TO_TICKS(100)) != pdPASS) {
        ESP_LOGE("scan task", "Queue vol!");
      }

      break;

    case BLE_GAP_EVENT_DISC_COMPLETE:
      ESP_LOGI("BLE", "Scan complete");
      break;
  }
  return 0;
}
void StartBleScan(uint32_t duration_ms) {
  struct ble_gap_disc_params scan_params;

  // Default scan configuration
  scan_params.filter_duplicates = 1;
  scan_params.passive = 1;
  scan_params.itvl = 0;
  scan_params.window = 0;
  scan_params.filter_policy = BLE_HCI_SCAN_FILT_NO_WL;
  scan_params.limited = 0;

  // Ensure the host is synced before scanning
  if (!ble_hs_synced()) {
    ESP_LOGE("BLE", "Cannot scan: Host not synced");
    return;
  }

  int rc = ble_gap_disc(BLE_OWN_ADDR_PUBLIC, duration_ms, &scan_params,
                        ble_gap_event_handler, NULL);
  if (rc != 0) {
    ESP_LOGE("BLE", "Error starting scan; rc=%d", rc);
  }
}

void TryConnectToWifiAndServer(void* pvParameters) {
  bool lastWifiState = false;
  communicationStateGroup = xEventGroupCreate();

  // Wi-Fi configuratie
  wifi_config_t wifi_config = {};
  strcpy((char*)wifi_config.sta.ssid, WIFI_SSID_1);
  strcpy((char*)wifi_config.sta.password, WIFI_PASSWORD_1);
  ESP_ERROR_CHECK(esp_wifi_set_config(WIFI_IF_STA, &wifi_config));
  esp_wifi_connect();

  while (1) {
    esp_netif_ip_info_t ip_info;
    esp_netif_t* netif = esp_netif_get_handle_from_ifkey("WIFI_STA_DEF");

    if (esp_netif_get_ip_info(netif, &ip_info) == ESP_OK &&
        ip_info.ip.addr != 0) {
      xEventGroupSetBits(communicationStateGroup, WIFI_CONNECTED_BIT);
      if (lastWifiState == false) {
        ButtonEventT event = EVENT_WIFI_CONNECTED;
        lastWifiState = true;
        xQueueSend(menuQueue, &event, portMAX_DELAY);
      }

      // Stap 2: Probeer de server te "pingen" via een TCP socket
      struct sockaddr_in dest_addr;
      dest_addr.sin_addr.s_addr = inet_addr(SERVER_IP);
      dest_addr.sin_family = AF_INET;
      dest_addr.sin_port = htons(SERVER_PORT);

      int sock = socket(AF_INET, SOCK_STREAM, IPPROTO_IP);
      if (sock < 0) {
        ESP_LOGE("SERVER", "Socket aanmaken mislukt");
      } else {
        // Zet een timeout op de verbinding (2 seconden)
        struct timeval tv = {.tv_sec = 2, .tv_usec = 0};
        setsockopt(sock, SOL_SOCKET, SO_SNDTIMEO, &tv, sizeof(tv));

        int err =
            connect(sock, (struct sockaddr*)&dest_addr, sizeof(dest_addr));
        if (err == 0) {
          ESP_LOGI("SERVER", "Server bereikbaar (Ping OK)");
          xEventGroupSetBits(communicationStateGroup, SERVER_CONNECTED_BIT);
          TimeSync::Init();
          TimeSync::Sync();
        } else {
          ESP_LOGW("SERVER", "Server niet bereikbaar");
          xEventGroupClearBits(communicationStateGroup, SERVER_CONNECTED_BIT);
        }
        close(sock);
        ButtonEventT event = EVENT_WIFI_CONNECTED;
        lastWifiState = true;
        xQueueSend(menuQueue, &event, portMAX_DELAY);
      }
    } else {
      // Geen Wi-Fi
      xEventGroupClearBits(communicationStateGroup,
                           WIFI_CONNECTED_BIT | SERVER_CONNECTED_BIT);

      if (lastWifiState == true) {
        ButtonEventT event = EVENT_WIFI_DISCONNECTED;
        lastWifiState = false;
        xQueueSend(menuQueue, &event, portMAX_DELAY);
      }

      // Switch to the next SSID in the list
      currentMyWifiNetworksIndex =
          (currentMyWifiNetworksIndex + 1) % MAX_NETWORKS;

      wifi_config_t wifi_config = {};
      strncpy((char*)wifi_config.sta.ssid,
              myWifiNetworks[currentMyWifiNetworksIndex].ssid, 32);
      strncpy((char*)wifi_config.sta.password,
              myWifiNetworks[currentMyWifiNetworksIndex].password, 64);

      ESP_LOGI("WIFI", "Switching to: %s",
               myWifiNetworks[currentMyWifiNetworksIndex].ssid);

      esp_wifi_disconnect();
      esp_wifi_set_config(WIFI_IF_STA, &wifi_config);
      esp_wifi_connect();
    }
    vTaskDelay(pdMS_TO_TICKS(10000));  // Probeer elke 10 seconden opnieuw
  }
}

void ScannerTask(void* pvParameters) {
  while (1) {
    wifi_scan_config_t scanConfig = {
        .ssid = NULL,
        .bssid = NULL,
        .channel = 0,
        .show_hidden = false,
        .scan_type = WIFI_SCAN_TYPE_ACTIVE,
        //.scan_type = WIFI_SCAN_TYPE_PASSIVE,
        .scan_time = {.active = {.min = 0, .max = 100}},
        .coex_background_scan = false};

    if (GlobalScanConfig.wifi2_4Ghz && !GlobalScanConfig.wifi5Ghz) {
      scanConfig.channel_bitmap.ghz_2_channels = 0x3ffe;
      scanConfig.channel_bitmap.ghz_5_channels = 0;
      printf("2.4\n");
    } else if (!GlobalScanConfig.wifi2_4Ghz && GlobalScanConfig.wifi5Ghz) {
      scanConfig.channel_bitmap.ghz_2_channels = 0;
      scanConfig.channel_bitmap.ghz_5_channels = 0xfeffffe;
      printf("5\n");
    } else if (GlobalScanConfig.wifi2_4Ghz && GlobalScanConfig.wifi5Ghz) {
      scanConfig.channel_bitmap.ghz_2_channels = 0x3ffe;
      scanConfig.channel_bitmap.ghz_5_channels = 0xfeffffe;
      printf("alles\n");
    }
    // bitmap scannen werkt wel maar het toont ook andere kanalen als die als
    // secondary of primary staan.

    // wifi scannen
    if (GlobalScanConfig.wifi2_4Ghz || GlobalScanConfig.wifi5Ghz) {
      PrintConfiguredChannels(&scanConfig);
      printf("free heap: %ld\n", esp_get_free_heap_size());

      uint64_t timeStart = TimeSync::Get();
      esp_err_t ret = esp_wifi_scan_start(&scanConfig, true);
      if (ret == ESP_ERR_WIFI_STATE) {
        ESP_LOGE("SCAN", "Wifi status onjuist, is hij wel geinitialiseerd?");
      } else if (ret == ESP_ERR_NO_MEM) {
        ESP_LOGE("SCAN", "GEEN GEHEUGEN!  heap bezet.");
      } else if (ret != ESP_OK) {
        ESP_LOGE("SCAN", "Scan fout: %s", esp_err_to_name(ret));
      }
      uint64_t timeEnd = TimeSync::Get();
      printf("scan klaar\n");

      uint16_t apCount = 0;
      esp_wifi_scan_get_ap_num(&apCount);
      if (apCount == 0) {
        ESP_LOGI("scanner task: ", "Geen netwerken gevonden.");
        continue;
      }

      ESP_LOGI("scanner task: ", "Aantal gevonden: %d", apCount);

      wifi_ap_record_t* apRecords =
          (wifi_ap_record_t*)malloc(sizeof(wifi_ap_record_t) * apCount);

      if (apRecords == NULL) {
        ESP_LOGE("scanner task", "Malloc faalde! Te weinig geheugen.");
        continue;
      }
      // lees uit wifi geheugen.
      if (esp_wifi_scan_get_ap_records(&apCount, apRecords) == ESP_OK) {
        ESP_LOGI("scan task", "Gevonden netwerken: %d", apCount);

        scanWifiResults_t results;
        results.records = apRecords;
        results.count = apCount;
        results.timeStart = timeStart;
        results.timeEnd = timeEnd;

        printf("scan time: %lld\n", (timeEnd - timeStart));

        if (xQueueSend(wifiQueue, &results, pdMS_TO_TICKS(100)) != pdPASS) {
          ESP_LOGE("scan task", "Queue vol! Data verwijderen.");
          free(apRecords);
        }
      } else {
        ESP_LOGE("scan task", "get_ap_records failed.\n");
        free(apRecords);  // Altijd free-en als get_records faalt
      }
    }

    // bluethooth
    if (GlobalScanConfig.bluetooth) {
      ESP_LOGI("SCAN", "Starting BLE Scan...");
      StartBleScan(5000);  // Scan for 5 seconds
    }

    vTaskDelay(pdMS_TO_TICKS(10));
  }
}

void JsonBuilderTask(void* pvParameters) {
  scanWifiResults_t wifiData;
  scanBluethoothResults_t btData;
  const int networkPostCount = 10;
  const int bluethoothPostCount = 10;
  QueueSetMemberHandle_t activeQueue;

  while (1) {
    activeQueue = xQueueSelectFromSet(combinedQueueSet, portMAX_DELAY);

    if (activeQueue == wifiQueue) {
      if (xQueueReceive(wifiQueue, &wifiData, 0) == pdPASS) {
        // Verwerk WiFi resultaten
        ESP_LOGI("JSON", "Bezig met verwerken van %d APs", wifiData.count);
        int32_t x = waitForUserNumber();
        int32_t y = waitForUserNumber();
        for (int i = 0; i < wifiData.count / networkPostCount; i++) {
          uint8_t start = i * networkPostCount;
          uint8_t count = networkPostCount;
          uint8_t verschil = (wifiData.count - (start + count));
          if (verschil < 10) {
            count = count + verschil;
          }

          char* payload =
              CreatWifiJson(wifiData.records, start, count, wifiData.timeStart,
                            wifiData.timeEnd, x, y);
          int8_t respons;
          if (payload != NULL) {
            respons = SendJsonPost(payload, serverUrl);
            if (respons == 0) {
              ESP_LOGI("JSON", "Data verzonden naar server.");
            } else {
              ESP_LOGI("JSON", "Data niet verzonden naar server.");
            }

            free(payload);
          } else {
            ESP_LOGI("json builder task", "payload was empty");
          }
        }

        free(wifiData.records);
      }
    }

    else if (activeQueue == BluetoothQueue) {
      // Verwerk Bluetooth resultaten
      if (uxQueueMessagesWaiting(BluetoothQueue) >= bluethoothPostCount) {
        // Haal ze er alle 10 uit in een loop

        printf("Batch van 10 Bluetooth resultaten verwerkt!\n");
      }
    } else {
      UBaseType_t waiting = uxQueueMessagesWaiting(BluetoothQueue);

      for (int i = 0; i < waiting; i++) {
        xQueueReceive(BluetoothQueue, &btData, 0);
        // Voeg toe aan verzendlijst...
      }
    }
  }
}
void DrawMenu(const char* menuOptions[], int8_t menuIndex) {
  int option1 = 0x0000;
  int option2 = 0x0000;
  int option3 = 0x0000;
  int option4 = 0x0000;

  if (menuIndex == 1) {
    option1 = 0x000f;
  } else if (menuIndex == 2) {
    option2 = 0x000f;
  } else if (menuIndex == 3) {
    option3 = 0x000f;
  } else if (menuIndex == 4) {
    option4 = 0x000f;
  }

  DrawStringFast(0, 50, menuOptions[0], 0xffff, option1, 3);
  DrawStringFast(0, 80, menuOptions[1], 0xffff, option2, 3);
  DrawStringFast(0, 110, menuOptions[2], 0xffff, option3, 3);
  DrawStringFast(0, 140, menuOptions[3], 0xffff, option4, 3);

  int square1 = 0x001F;
  int square2 = 0x001F;
  int square3 = 0x001F;
  int square4 = 0x001F;

  // crasht niet door "Lazy Evaluation"
  if (GlobalScanConfig.wifi2_4Ghz) {
    square1 = 0x07E0;
  }
  if (GlobalScanConfig.wifi5Ghz) {
    square2 = 0x07E0;
  }
  if (GlobalScanConfig.bluetooth) {
    square3 = 0x07E0;
  }
  if (xMonitorCpuHandle) {
    square4 = 0x07E0;
  }

  DrawRectFilled(200, 55, 15, 15, 0x738E, square1, 2);
  DrawRectFilled(200, 85, 15, 15, 0x738E, square2, 2);
  DrawRectFilled(200, 115, 15, 15, 0x738E, square3, 2);
  DrawRectFilled(200, 145, 15, 15, 0x738E, square4, 2);
}

void ToggleSelect(int8_t menuIndex) {
  if (menuIndex == 4) {
    if (xMonitorCpuHandle == NULL) {
      xTaskCreate(MonitorCpuTask, "MonitorCpuTask", 4096, NULL, 5,
                  &xMonitorCpuHandle);
    } else {
      vTaskDelete(xMonitorCpuHandle);
      xMonitorCpuHandle = NULL;
    }
    return;
  }

  if (xScannerHandle == NULL) {
    xTaskCreate(ScannerTask, "ScannerTask", 4096, NULL, 5, &xScannerHandle);
  }
  // WIFI 2.4Ghz
  if (menuIndex == 1) {
    if (GlobalScanConfig.wifi2_4Ghz) {
      GlobalScanConfig.wifi2_4Ghz = false;
    } else {
      GlobalScanConfig.wifi2_4Ghz = true;
    }
  }

  // WIFI 5Ghz
  else if (menuIndex == 2) {
    if (GlobalScanConfig.wifi5Ghz) {
      GlobalScanConfig.wifi5Ghz = false;
    } else {
      GlobalScanConfig.wifi5Ghz = true;
    }
  }

  // BLUETOOTH
  else if (menuIndex == 3) {
    if (GlobalScanConfig.bluetooth) {
      GlobalScanConfig.bluetooth = false;
    } else {
      GlobalScanConfig.bluetooth = true;
    }
  }
}
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
extern "C" void app_main(void) {
  // initArduino();
  printf("Hello World!\n");
  printf("Build Date: %s\n", __DATE__);
  printf("Build Time: %s\n", __TIME__);

  LocationMutex = xSemaphoreCreateMutex();
  menuQueue = xQueueCreate(15, sizeof(ButtonEventT));
  if (menuQueue == NULL) {
    ESP_LOGE("INIT", "Fatal: Could not create menuQueue!");
    return;
  }
  GpioSetup();

  esp_err_t status = InitWifiBluethooth();
  if (status != ESP_OK) {
    ESP_LOGE(LOGTAG, "Radio initialisatie mislukt!");
    return;
  }

  wifiQueue = xQueueCreate(5, sizeof(scanWifiResults_t));
  BluetoothQueue = xQueueCreate(50, sizeof(scanBluethoothResults_t));

  combinedQueueSet = xQueueCreateSet(5 + 50);
  xQueueAddToSet(wifiQueue, combinedQueueSet);
  xQueueAddToSet(BluetoothQueue, combinedQueueSet);

  xTaskCreate(MenuTask,    // Naam van de functie
              "MenuTask",  // Naam voor debugging
              3096,        // Stack size in bytes
              NULL,        // Parameter die je mee wilt geven (optioneel)
              5,           // Prioriteit (hoger getal = hogere prioriteit)
              NULL  // Task handle (optioneel, om de task later aan te sturen)
  );
  xTaskCreate(TryConnectToWifiAndServer, "TryConnectToWifiAndServer", 4096,
              NULL, 5,
              NULL  //
  );
  // ota upload is sneller dan usb
  xTaskCreate(OtaWebserverTask, "ota server", 4096, NULL, 20, NULL);

  xTaskCreate(JsonBuilderTask, "json builder", 4096, NULL, 5, NULL);

  CheckCpuFreq();
}

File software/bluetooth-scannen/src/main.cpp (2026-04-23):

#include <Arduino.h>
#include <BLEDevice.h>
#include <BLEUtils.h>
#include <BLEScan.h>
#include <BLEAdvertisedDevice.h>

BLEScan* pBLEScan;

int scanTime = 5; // scan tijd in seconden

class MyAdvertisedDeviceCallbacks: public BLEAdvertisedDeviceCallbacks {
    void onResult(BLEAdvertisedDevice advertisedDevice) {
        // print one JSON object per device (newline separated)
        String name = advertisedDevice.getName().c_str();
        String addr = advertisedDevice.getAddress().toString().c_str();
        int rssi = advertisedDevice.getRSSI();

        // escape quotes in name/address if needed (very simple)
        name.replace("\"","\\\"");
        addr.replace("\"","\\\"");

        Serial.print("{\"name\":\"");
        Serial.print(name);
        Serial.print("\",\"address\":\"");
        Serial.print(addr);
        Serial.print("\",\"rssi\":");
        Serial.print(rssi);
        Serial.println("}");
    }
};

void setup() {
    Serial.begin(115200);
    Serial.println("BLE Scanner gestart...");

    BLEDevice::init("");
    pBLEScan = BLEDevice::getScan();
    pBLEScan->setAdvertisedDeviceCallbacks(new MyAdvertisedDeviceCallbacks());
    pBLEScan->setActiveScan(true); // Actief scannen (meer data, iets meer stroom)
}

void loop() {
    Serial.println("Scannen...");
    // indicate start of scan so host can group results
    Serial.println("SCAN_START");

    BLEScanResults foundDevices = pBLEScan->start(scanTime, false);
    Serial.print("Aantal apparaten gevonden: ");
    Serial.println(foundDevices.getCount());
    Serial.println("Scan klaar!\n");

    // mark end of this scan batch
    Serial.println("SCAN_END");

    delay(10000); // wacht 10 sec voor volgende scan
}

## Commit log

2026-04-23 fixed bug in fingerprinting.py
2026-04-24 findLocation elke locatie weet hoe goed het overeen komt
2026-04-25 doc fingerprint.py
2026-04-25 nieuwe scans krijgen nu een locatie
2026-04-30 adjustment to endpoints to heatmap table
2026-04-30 no location found bug
    [main.cpp]
2026-04-30 documentatie voor het menu en hoe het werkt
2026-04-30 location over writing bug fix
    [main.cpp]
2026-04-30 code voor real time op de esp
2026-04-30 Datum filter
2026-05-07 Update API documentation for upload endpoint and add fingerprinting documentation
2026-05-07 Update fingerprinting documentation with detailed function descriptions
2026-05-07 manueel toevoegen fingerprint
2026-05-18 Fix typos in device menu and app.py documentation
2026-05-18 Update documentation for API, device menu, HTTP POST, OTA server, screen, and time synchronization
2026-05-19 Update documentation for app.py and fingerprint.py, enhancing clarity on server functionality and location determination processes.
